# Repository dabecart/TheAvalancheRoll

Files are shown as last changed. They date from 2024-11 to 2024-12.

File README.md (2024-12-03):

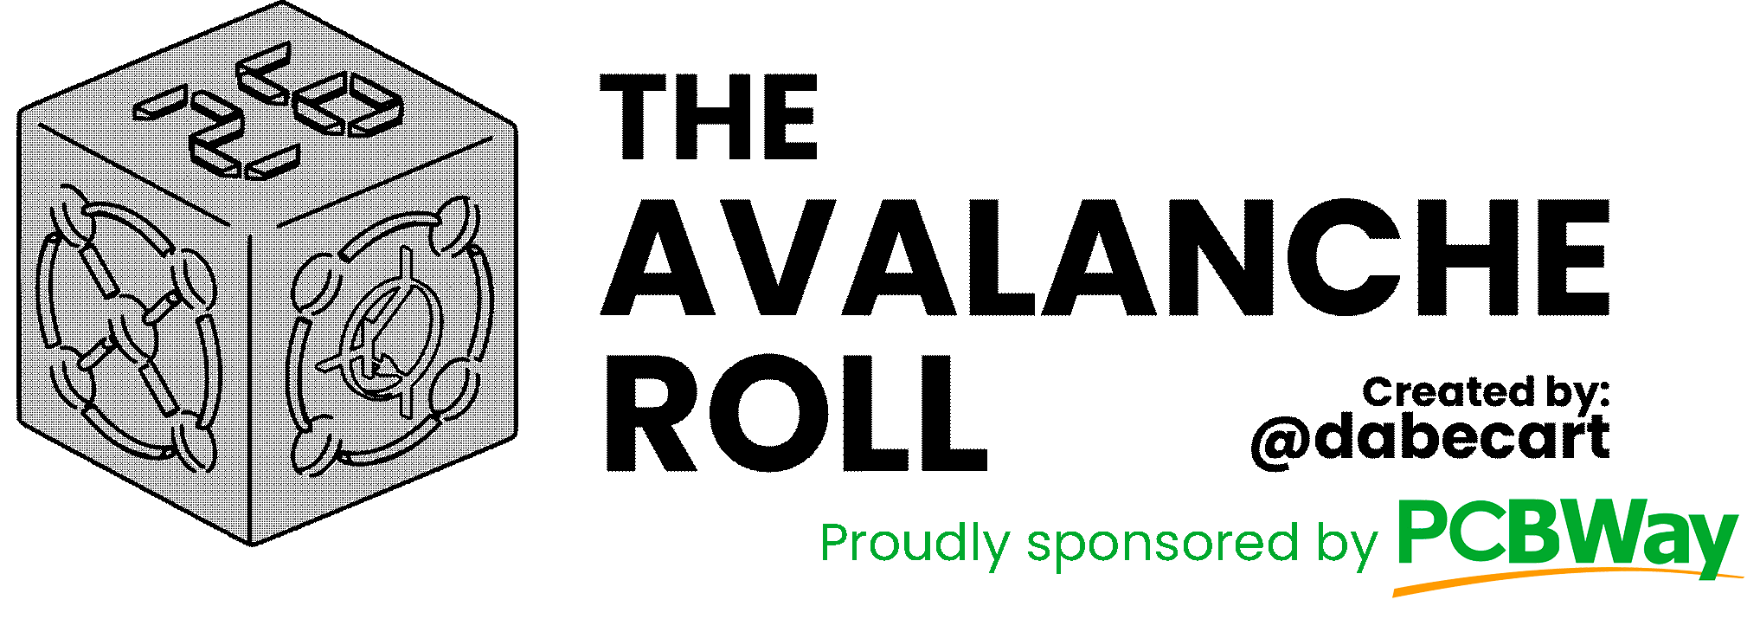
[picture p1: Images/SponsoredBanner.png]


This project was sponsored by [**PCBWay**](#pcbway---pcb-manufacturing-and-assembly)!

# What's **THE AVALANCHE ROLL**?

The Avalanche Roll is the latest (_useless_) invention of @dabecart, and now there's [version 2.0 of this project](#the-avalanche-roll-v20)!

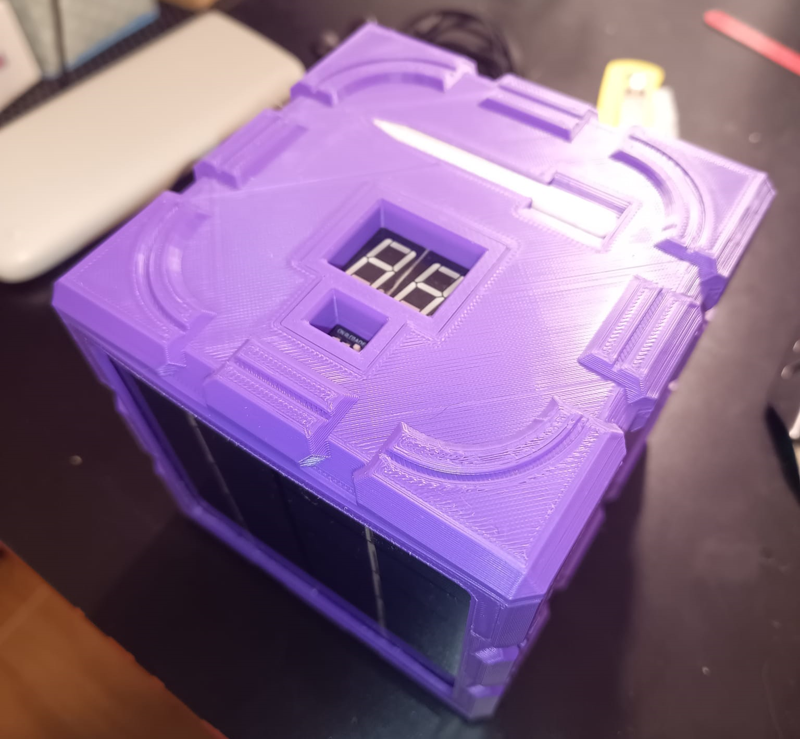
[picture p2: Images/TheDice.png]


It's a space-graded truly-random and up to **D32** electronic dice that operates on a quantum operated phenomenon called **avalanche effect**!

Yes, you've heard it right, avalanche! That's where the name of this hunk of plastic and electronic comes… Genius, Daniel… Genius.

So, the avalanche effect happens when a N-P junction gets _reverse_ polarized, that is, when you try to force current over a diode on the opposite direction, from negative to positive. That, over a long period of time, causes a degrading of the diode, but in this case, we're looking for the exact point where the effect **starts** occurring.

You see, a diode generates a big voltage potential over its two ends when reverse polarized. Electrons cannot jump from one end to the other due to this potential; at least, not according to classical physics. Here comes the quantum part: there's an effect called **quantum tunneling** that actually allows the electrons to “appear” at the other side of the barrier, even though it's supposed to be impossible!

These jumps or magical apparitions are **truly random!** There's no way to calculate when the electrons are going to take the jump, and this is what makes this dice **really** random!

OK. And what about the **space-graded** part?

Well… This dice operates **without any microcontroller!** It's all analogic components and logic gates, meaning that this dice can go to outer space! (I think?) It's one of the requisites, but yeah, it could go to space (I think????).

Oh, and you can select the number of “faces” of the dice! Meaning you can ditch all your boring dices, because you've got one to rule over all!

“But @dabecart, going to space? If it's battery operated, how are you going to charge it?”

Glad you've asked it. It's got a **solar panel**. Yeah… It can also be charged using **USB-C**!

Useless. Over-engineered. Dubious quality. All seals of @dabecart work!

Hope you enjoy it!

# How to use

Please, refer to the [user guide](TheAvalancheRoll_UserGuide.pdf). Thanks!

# How to build it

1. Order (or build) the PCBs. You can find schematics and gerber files in the [PCB folder](PCB).
2. Once you have the PCBs, locate all elements on the boards. You can find a full BOM [here](BOM/TotalBOM.xlsx).
3. Print all the `stl` files. You can locate them [here](3d/stl).
4. Read the [assembly manual](TheAvalancheRoll_AssemblyManual.pdf) and done!

# The Avalanche Roll: v.2.0
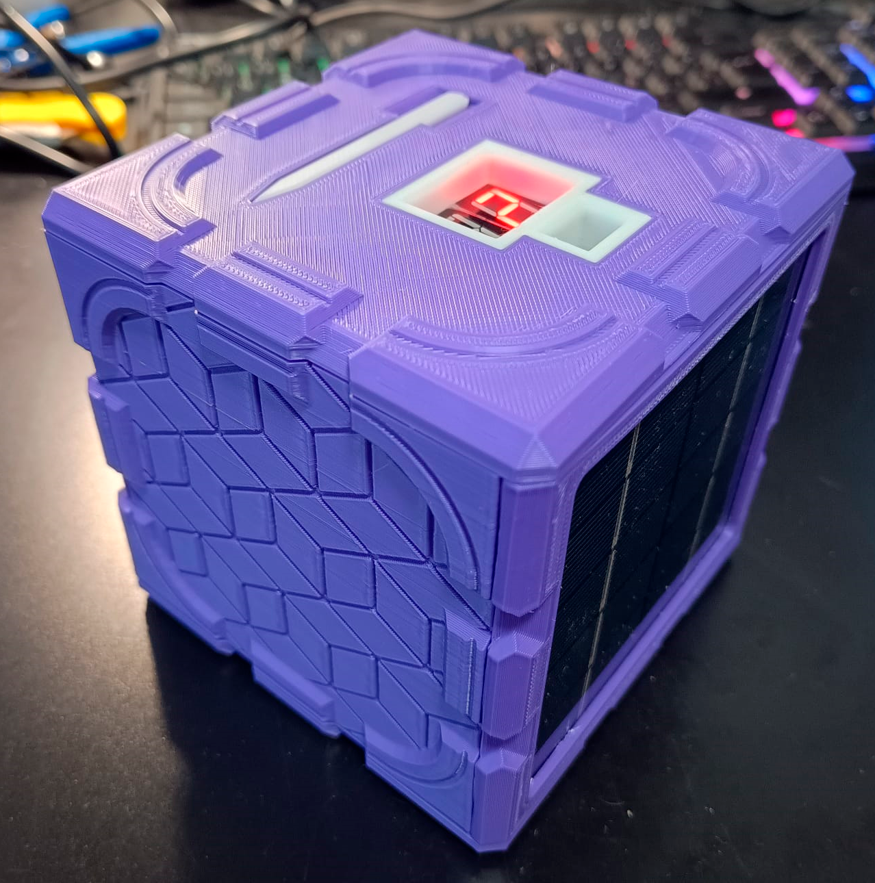
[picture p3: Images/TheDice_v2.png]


When I first launched this project I was really surprised to be approached by the fine gentlemen at PCBWay to sponsor this project. Thanks to them:
- I have been able to fix some of the minor bugs I found on the first version of the dice, such as sporadic number bursts. 
- I've made the power board into a PCB! Yipee! 
- New look! I've also added new patters to the structure of the dice. Hope you like it!

# Photo album

Check the [Google Photos album](https://photos.app.goo.gl/XxesUJSZd3JCvjf18) with photos and a video of the project!



# PCBWay - PCB Manufacturing and Assembly
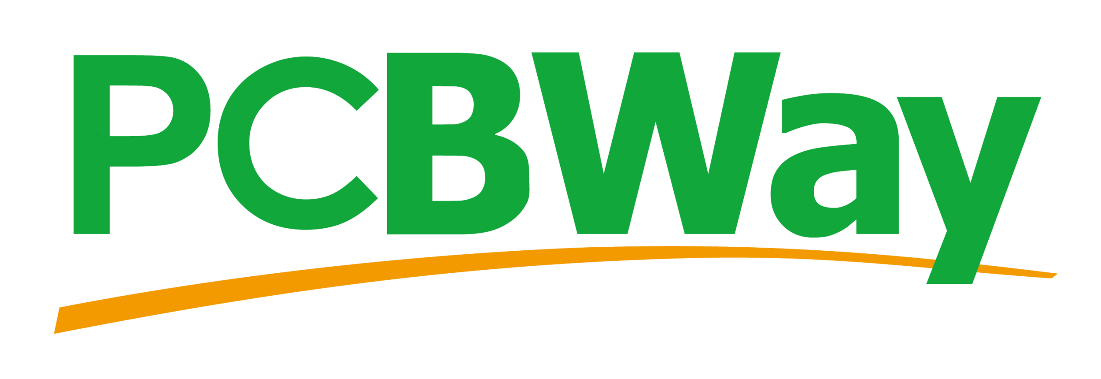
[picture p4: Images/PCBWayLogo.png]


🌟 A Huge Thank You to PCBWay! 🌟

Thanks to PCBWay for their incredible support in bringing the second version of The Avalanche Roll to life. Whether you're a hobbyist, engineer, or student, I feel confident in saying that they're the go-to destination for high-quality PCB manufacturing and prototyping.

Here are just a few of the reasons why PCBWay stands out:

✅ Top-notch Quality: After thoroughly inspecting all of the PCBs of my project, I was content with the great precision the PCBs were made. I felt they are reliable and durable!

✅ Fast Turnaround: The whole ordering, manufacturing and shipping of 50 PCBs to Spain took around a week and a half, which is most impressing! 

✅ Affordable Pricing: Their competitive rates make professional-grade PCBs accessible to everyone. To give you an example, an Avalanche Roll PCB's took less than $5 to build, that is five different PCBs and I'm also counting the shipping, amazing!

✅ Excellent Support: From order placement to final delivery, PCBWay’s team was always there to answer my questions and provide guidance.

Thanks to their expertise and dedication, I was able to turn my ideas for this project into reality without a hitch. If you’re working on your next PCB project, I can’t recommend PCBWay enough!

🎉 Visit [**PCBWay.com**](https://www.pcbway.com/) and experience their amazing service for yourself!

# License
This project is licensed under MIT License. Read the [LICENSE file](LICENSE).

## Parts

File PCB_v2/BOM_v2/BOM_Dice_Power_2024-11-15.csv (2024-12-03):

ID | Name | Designator | Quantity
1 | JST-XH-02 | X5,X4,X3,X2,X1,X6 | 6
2 | LIPO BATTERY CHARGE | U3 | 1
3 | Boost-Converter | U2,U1 | 2
4 | 1N5819RLG | D1,D2 | 2

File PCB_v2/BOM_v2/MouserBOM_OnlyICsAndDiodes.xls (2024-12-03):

THEAVALANCHEROLL
Mouser No | Mfr. No | Manufacturer | Customer No | Description | RoHS | Lifecycle | Order Qty. | Price (EUR) | Ext.: (EUR)
512-1N4148 | 1N4148 | onsemi |  | Small Signal Switching Diodes 100V Io/200mA BULK | RoHS Compliant By Exemption |  | 2 | 0,093 € | 0,19 €
637-1N5819 | 1N5819 | Diotec Semiconductor |  | Schottky Diodes & Rectifiers Schottky, DO-15, 40V, 1A | RoHS Compliant By Exemption |  | 2 | 0,158 € | 0,32 €
637-2N3904 | 2N3904 | Diotec Semiconductor |  | Bipolar Transistors - BJT BJT, TO-92, 40V, 200mA, NPN | RoHS Compliant |  | 2 | 0,093 € | 0,19 €
637-2N7000 | 2N7000 | Diotec Semiconductor |  | MOSFETs MOSFET, TO-92, 60V, 0.2A, 150C, N | RoHS Compliant |  | 38 | 0,112 € | 4,26 €
625-BZX85C5V1-TAP | BZX85C5V1-TAP | Vishay |  | Zener Diodes 5.1 Volt 1.3 Watt 5% | RoHS Compliant By Exemption |  | 1 | 0,186 € | 0,19 €
595-LM324N | LM324N | Texas Instruments |  | Operational Amplifiers - Op Amps Quad | RoHS Compliant |  | 1 | 0,316 € | 0,32 €
595-LM358AP | LM358AP | Texas Instruments |  | Operational Amplifiers - Op Amps Dual | RoHS Compliant |  | 1 | 0,233 € | 0,23 €
595-NE555P | NE555P | Texas Instruments |  | Timers & Support Products Precision | RoHS Compliant |  | 4 | 0,316 € | 1,26 €
512-SS8550DBU | SS8550DBU | onsemi |  | Bipolar Transistors - BJT TO92 PNP 2W BULK | RoHS Compliant |  | 2 | 0,242 € | 0,48 €
595-SN74HC02AN | SN74HC02AN | Texas Instruments |  | Logic Gates | RoHS Compliant |  | 1 | 0,512 € | 0,51 €
595-SN74AHC14N | SN74AHC14N | Texas Instruments |  | Inverters Hex Schmitt-Trigger | RoHS Compliant |  | 2 | 0,372 € | 0,74 €
595-SN74ACT08N | SN74ACT08N | Texas Instruments |  | Logic Gates Quad 2-Input Pos | RoHS Compliant |  | 9 | 0,484 € | 4,36 €
595-SN74HC393N | SN74HC393N | Texas Instruments |  | Counter ICs Dual 4-Bit Binary | RoHS Compliant |  | 1 | 0,512 € | 0,51 €
595-SN74AC86N | SN74AC86N | Texas Instruments |  | Logic Gates Quad 2 Input | RoHS Compliant |  | 1 | 0,465 € | 0,47 €
595-SN74F32N | SN74F32N | Texas Instruments |  | Logic Gates Quad 2-input Positive-OR gates | RoHS Compliant |  | 8 | 0,493 € | 3,94 €

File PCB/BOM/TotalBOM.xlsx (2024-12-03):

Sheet: Sheet3
Row Labels | Sum of Quantity | Price/Item | Price
0.1u | 9 | 0.00 € | 0.00 €
100k | 4 | 0.00 € | 0.00 €
100u | 1 | 0.00 € | 0.00 €
10k | 32 | 0.00 € | 0.00 €
1k | 1 | 0.00 € | 0.00 €
1M | 5 | 0.00 € | 0.00 €
1N4148 | 2 | 0.02 € | 0.04 €
1u | 7 | 0.00 € | 0.00 €
200k | 1 | 0.00 € | 0.00 €
220 | 15 | 0.00 € | 0.00 €
220k | 3 | 0.00 € | 0.00 €
2N3904 | 2 | 0.08 € | 0.16 €
2N7000 | 38 | 0.20 € | 7.45 €
4.7k | 2 | 0.00 € | 0.00 €
4.7u | 1 | 0.00 € | 0.00 €
470k | 3 | 0.00 € | 0.00 €
47k | 2 | 0.00 € | 0.00 €
47n | 2 | 0.00 € | 0.00 €
500k | 1 | 0.00 € | 0.00 €
AlwaysOn | 1 | 0.00 € | 0.00 €
BZX85C5V1 | 1 | 0.15 € | 0.15 €
Digit0 | 1 | 0.20 € | 0.20 €
Digit1 | 1 | 0.20 € | 0.20 €
FromBToA | 2 | 0.00 € | 0.00 €
FromCToB | 2 | 0.00 € | 0.00 €
FromDToC | 2 | 0.00 € | 0.00 €
FromLayerB | 1 | 0.00 € | 0.00 €
FromLayerC | 1 | 0.00 € | 0.00 €
JST-XH-02 | 6 | 0.02 € | 0.12 €
JST-XH-04 | 1 | 0.02 € | 0.02 €
Layer A-B | 1 | 0.00 € | 0.00 €
LM324 | 1 | 0.34 € | 0.34 €
LM358AP | 1 | 0.21 € | 0.21 €
ManualThrow | 1 | 0.00 € | 0.00 €
NC_Tilt | 1 | 0.13 € | 0.13 €
ND_Tilt | 1 | 0.00 € | 0.00 €
NE555P | 4 | 0.38 € | 1.52 €
S8550 | 2 | 0.25 € | 0.50 €
S9014 | 1 | 0.25 € | 0.25 €
S9015 | 3 | 0.25 € | 0.75 €
SN74HC02N | 1 | 0.61 € | 0.61 €
SN74HC04N | 2 | 0.64 € | 1.28 €
SN74HC08N | 9 | 0.64 € | 5.78 €
SN74HC393N | 1 | 0.64 € | 0.64 €
SN74HC86NE4 | 1 | 0.64 € | 0.64 €
SN74HCT32N | 8 | 0.64 € | 5.14 €
SW-520D | 2 | 0.65 € | 1.30 €
Switch | 1 | 0.50 € | 0.50 €
TestPad | 4 | 0.00 € | 0.00 €
ToLayerA | 3 | 0.00 € | 0.00 €
Grand Total | 198 |  | 27.96 €
 | Manufacturing

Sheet: BOM
Source.Name | ID | Name | Designator | Quantity
BOM_Dice_LayerA_2024-10-03.csv | 1 | JST-XH-02 | X2,X1 | 2
BOM_Dice_LayerA_2024-10-03.csv | 2 | TestPad | U3 | 1
BOM_Dice_LayerA_2024-10-03.csv | 3 | 2N7000 | Q22,Q23,Q24,Q25,Q1,Q2,Q3,Q4,Q5,Q6,Q7,Q8,Q9,Q10,Q11,Q12,Q13,Q14,Q15,Q16,Q17,Q18,Q19,Q20,Q21 | 25
BOM_Dice_LayerA_2024-10-03.csv | 4 | 1u | C1 | 1
BOM_Dice_LayerA_2024-10-03.csv | 5 | FromBToA | J1 | 1
BOM_Dice_LayerA_2024-10-03.csv | 6 | Layer A-B | J2 | 1
BOM_Dice_LayerA_2024-10-03.csv | 7 | 220 | R1,R2,R3,R4,R5,R6,R7,R8,R9,R10,R11,R12,R13,R14 | 14
BOM_Dice_LayerA_2024-10-03.csv | 8 | 10k | R15,R16,R17,R18,R19,R20,R21,R22,R23 | 9
BOM_Dice_LayerA_2024-10-03.csv | 9 | Digit0 | SEG0 | 1
BOM_Dice_LayerA_2024-10-03.csv | 10 | Digit1 | SEG1 | 1
BOM_Dice_LayerA_2024-10-03.csv | 11 | Switch | U1 | 1
BOM_Dice_LayerA_2024-10-03.csv | 12 | SN74HC86NE4 | U2 | 1
BOM_Dice_LayerB_2024-10-03.csv | 1 | TestPad | U11 | 1
BOM_Dice_LayerB_2024-10-03.csv | 2 | JST-XH-02 | X1 | 1
BOM_Dice_LayerB_2024-10-03.csv | 3 | 1u | C1 | 1
BOM_Dice_LayerB_2024-10-03.csv | 4 | ToLayerA | H1 | 1
BOM_Dice_LayerB_2024-10-03.csv | 5 | FromBToA | H2 | 1
BOM_Dice_LayerB_2024-10-03.csv | 6 | FromLayerC | J1 | 1
BOM_Dice_LayerB_2024-10-03.csv | 7 | FromCToB | J2 | 1
BOM_Dice_LayerB_2024-10-03.csv | 8 | 2N7000 | Q1 | 1
BOM_Dice_LayerB_2024-10-03.csv | 9 | 10k | R1 | 1
BOM_Dice_LayerB_2024-10-03.csv | 10 | SN74HC08N | U1,U3,U4,U6 | 4
BOM_Dice_LayerB_2024-10-03.csv | 11 | SN74HCT32N | U5,U7,U8,U9,U10 | 5
BOM_Dice_LayerB_2024-10-03.csv | 12 | SN74HC04N | U2 | 1
BOM_Dice_LayerC_2024-10-03.csv | 1 | JST-XH-02 | X1 | 1
BOM_Dice_LayerC_2024-10-03.csv | 2 | TestPad | U11 | 1
BOM_Dice_LayerC_2024-10-03.csv | 3 | FromDToC | J3 | 1
BOM_Dice_LayerC_2024-10-03.csv | 4 | FromLayerB | J1 | 1
BOM_Dice_LayerC_2024-10-03.csv | 5 | 1u | C1 | 1
BOM_Dice_LayerC_2024-10-03.csv | 6 | FromCToB | H2 | 1
BOM_Dice_LayerC_2024-10-03.csv | 7 | FromDToC | J2 | 1
BOM_Dice_LayerC_2024-10-03.csv | 8 | SN74HC04N | U1 | 1
BOM_Dice_LayerC_2024-10-03.csv | 9 | SN74HC08N | U2,U4,U5,U7,U9 | 5
BOM_Dice_LayerC_2024-10-03.csv | 10 | SN74HCT32N | U3,U6,U8 | 3
BOM_Dice_LayerD_2024-10-03.csv | 1 | JST-XH-02 |  | 2
BOM_Dice_LayerD_2024-10-03.csv | 2 | TestPad |  | 1
BOM_Dice_LayerD_2024-10-03.csv | 3 | JST-XH-04 |  | 1
BOM_Dice_LayerD_2024-10-03.csv | 4 | SW-520D |  | 2
BOM_Dice_LayerD_2024-10-03.csv | 5 | AlwaysOn |  | 1
BOM_Dice_LayerD_2024-10-03.csv | 6 | ManualThrow |  | 1
BOM_Dice_LayerD_2024-10-03.csv | 7 | ToLayerA |  | 1
BOM_Dice_LayerD_2024-10-03.csv | 8 | SN74HC02N |  | 1
BOM_Dice_LayerD_2024-10-03.csv | 9 | ToLayerA |  | 1
BOM_Dice_LayerD_2024-10-03.csv | 10 | ND_Tilt |  | 1
BOM_Dice_LayerD_2024-10-03.csv | 11 | NC_Tilt |  | 1
BOM_Dice_LayerD_2024-10-03.csv | 12 | 2N7000 |  | 12
BOM_Dice_LayerD_2024-10-03.csv | 13 | 100k |  | 4
BOM_Dice_LayerD_2024-10-03.csv | 14 | 220k |  | 3
BOM_Dice_LayerD_2024-10-03.csv | 15 | SN74HC393N |  | 1
BOM_Dice_LayerD_2024-10-03.csv | 16 | 47n |  | 2
BOM_Dice_LayerD_2024-10-03.csv | 17 | 0.1u |  | 9
BOM_Dice_LayerD_2024-10-03.csv | 18 | 4.7u |  | 1
BOM_Dice_LayerD_2024-10-03.csv | 19 | 1u |  | 4
BOM_Dice_LayerD_2024-10-03.csv | 20 | 100u |  | 1
BOM_Dice_LayerD_2024-10-03.csv | 21 | BZX85C5V1 |  | 1
BOM_Dice_LayerD_2024-10-03.csv | 22 | 1N4148 |  | 2
BOM_Dice_LayerD_2024-10-03.csv | 23 | 2N3904 |  | 2
BOM_Dice_LayerD_2024-10-03.csv | 24 | S9015 |  | 3
BOM_Dice_LayerD_2024-10-03.csv | 25 | S9014 |  | 1
BOM_Dice_LayerD_2024-10-03.csv | 26 | S8550 |  | 2
BOM_Dice_LayerD_2024-10-03.csv | 27 | 10k |  | 21
BOM_Dice_LayerD_2024-10-03.csv | 28 | 1M |  | 5
BOM_Dice_LayerD_2024-10-03.csv | 29 | 47k |  | 2
BOM_Dice_LayerD_2024-10-03.csv | 30 | 4.7k |  | 2
BOM_Dice_LayerD_2024-10-03.csv | 31 | 470k |  | 3
BOM_Dice_LayerD_2024-10-03.csv | 32 | 1k |  | 1
BOM_Dice_LayerD_2024-10-03.csv | 33 | 220 |  | 1
BOM_Dice_LayerD_2024-10-03.csv | 34 | 200k |  | 1
BOM_Dice_LayerD_2024-10-03.csv | 35 | 500k |  | 1
BOM_Dice_LayerD_2024-10-03.csv | 36 | 10k |  | 1
BOM_Dice_LayerD_2024-10-03.csv | 37 | NE555P |  | 4
BOM_Dice_LayerD_2024-10-03.csv | 38 | LM324 |  | 1
BOM_Dice_LayerD_2024-10-03.csv | 39 | LM358AP |  | 1

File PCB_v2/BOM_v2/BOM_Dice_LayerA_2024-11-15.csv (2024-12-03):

ID | Name | Designator | Quantity
1 | 2N7000 | Q22,Q23,Q24,Q25,Q1,Q2,Q3,Q4,Q5,Q6,Q7,Q8,Q9,Q10,Q11,Q12,Q13,Q14,Q15,Q16,Q17,Q18,Q19,Q20,Q21 | 25
2 | 1u | C1 | 1
3 | FromBToA | J1 | 1
4 | Layer A-B | J2 | 1
5 | 220 | R1,R2,R3,R4,R5,R6,R7,R8,R9,R10,R11,R12,R13,R14 | 14
6 | 10k | R15,R16,R17,R18,R19,R20,R21,R22,R23 | 9
7 | Digit0 | SEG0 | 1
8 | Digit1 | SEG1 | 1
9 | Switch | U1 | 1
10 | SN74HC86NE4 | U2 | 1
11 | JST-XH-02 | X2,X1 | 2
12 | TestPad | U3 | 1

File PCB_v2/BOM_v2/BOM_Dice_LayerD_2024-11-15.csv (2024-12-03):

ID | Name | Designator | Quantity
1 | JST-XH-02 | X3,X1 | 2
2 | TestPad | U11 | 1
3 | JST-XH-04 | X2 | 1
4 | SW-520D | U8,U6 | 2
5 | 0.22u | C7 | 1
6 | 0 | R46,R47 | 2
7 | 2.2u | C8 | 1
8 | 1M | R11,R3,R6,R9,R10,R29 | 6
9 | AlwaysOn | J3 | 1
10 | ManualThrow | J4 | 1
11 | ToLayerA | H2 | 1
12 | SN74HC02N | U12 | 1
13 | ToLayerA | H1 | 1
14 | ND_Tilt | J1 | 1
15 | NC_Tilt | J2 | 1
16 | 2N7000 | Q20,Q7,Q8,Q11,Q12,Q13,Q14,Q15,Q16,Q17,Q18,Q19 | 12
17 | 100k | R44,R13,R25,R34 | 4
18 | 220k | R45,R26,R35 | 3
19 | SN74HC393N | U10 | 1
20 | 47n | C1,C2 | 2
21 | 0.1u | C4,C5,C9,C13,C14,C15,C16,C17 | 8
22 | 4.7u | C3 | 1
23 | 1u | C6,C11,C12 | 3
24 | 100u | C10 | 1
25 | BZX85C5V1 | D1 | 1
26 | 1N4148 | D2,D3 | 2
27 | 2N3904 | Q1,Q2 | 2
28 | S9015 | Q3,Q5,Q9 | 3
29 | S9014 | Q4 | 1
30 | S8550 | Q6,Q10 | 2
31 | 10k | R1,R4,R7,R8,R15,R18,R19,R20,R21,R24,R27,R28,R30,R33,R36,R38,R39,R40,R41,R42,R43 | 21
32 | 47k | R5 | 1
33 | 4.7k | R12,R17 | 2
34 | 470k | R16,R32,R37 | 3
35 | 1k | R23 | 1
36 | 220 | R31 | 1
37 | 200k | R2 | 1
38 | 500k | R14 | 1
39 | 10k | R22 | 1
40 | NE555P | U2,U3,U5,U7 | 4
41 | LM324 | U1 | 1
42 | LM358AP | U4 | 1

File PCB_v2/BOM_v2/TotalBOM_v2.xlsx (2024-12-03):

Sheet: Sheet2
Row Labels | Sum of Quantity
0 | 2
0.1u | 8
0.22u | 1
100k | 4
100u | 1
10k | 32
1k | 1
1M | 6
1N4148 | 2
1N5819RLG | 2
1u | 6
2.2u | 1
200k | 1
220 | 15
220k | 3
2N3904 | 2
2N7000 | 38
4.7k | 2
4.7u | 1
470k | 3
47k | 1
47n | 2
500k | 1
AlwaysOn | 1 | x
Boost-Converter | 2
BZX85C5V1 | 1
Digit0 | 1
Digit1 | 1
FromBToA | 2 | x
FromCToB | 2 | x
FromDToC | 2 | x
FromLayerB | 1 | x
FromLayerC | 1 | x
JST-XH-02 | 12
JST-XH-04 | 1
Layer A-B | 1
LIPO BATTERY CHARGE | 1
LM324 | 1
LM358AP | 1
ManualThrow | 1 | x
NC_Tilt | 1 | x
ND_Tilt | 1 | x
NE555P | 4
S8550 | 2
S9014 | 1
S9015 | 3
SN74HC02N | 1
SN74HC04N | 2
SN74HC08N | 9
SN74HC393N | 1
SN74HC86NE4 | 1
SN74HCT32N | 8
SW-520D | 2
Switch | 1 | x
TestPad | 4 | x
ToLayerA | 3 | x
(blank) |  | x
Grand Total | 211

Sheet: BOM_v2
Source.Name | ID | Name | Designator | Quantity
BOM_Dice_LayerA_2024-11-15.csv | 1 | 2N7000 | Q22,Q23,Q24,Q25,Q1,Q2,Q3,Q4,Q5,Q6,Q7,Q8,Q9,Q10,Q11,Q12,Q13,Q14,Q15,Q16,Q17,Q18,Q19,Q20,Q21 | 25
BOM_Dice_LayerA_2024-11-15.csv | 2 | 1u | C1 | 1
BOM_Dice_LayerA_2024-11-15.csv | 3 | FromBToA | J1 | 1
BOM_Dice_LayerA_2024-11-15.csv | 4 | Layer A-B | J2 | 1
BOM_Dice_LayerA_2024-11-15.csv | 5 | 220 | R1,R2,R3,R4,R5,R6,R7,R8,R9,R10,R11,R12,R13,R14 | 14
BOM_Dice_LayerA_2024-11-15.csv | 6 | 10k | R15,R16,R17,R18,R19,R20,R21,R22,R23 | 9
BOM_Dice_LayerA_2024-11-15.csv | 7 | Digit0 | SEG0 | 1
BOM_Dice_LayerA_2024-11-15.csv | 8 | Digit1 | SEG1 | 1
BOM_Dice_LayerA_2024-11-15.csv | 9 | Switch | U1 | 1
BOM_Dice_LayerA_2024-11-15.csv | 10 | SN74HC86NE4 | U2 | 1
BOM_Dice_LayerA_2024-11-15.csv | 11 | JST-XH-02 | X2,X1 | 2
BOM_Dice_LayerA_2024-11-15.csv | 12 | TestPad | U3 | 1
BOM_Dice_LayerB_2024-11-15.csv | 1 | TestPad | U11 | 1
BOM_Dice_LayerB_2024-11-15.csv | 2 | JST-XH-02 | X1 | 1
BOM_Dice_LayerB_2024-11-15.csv | 3 | 1u | C1 | 1
BOM_Dice_LayerB_2024-11-15.csv | 4 | ToLayerA | H1 | 1
BOM_Dice_LayerB_2024-11-15.csv | 5 | FromBToA | H2 | 1
BOM_Dice_LayerB_2024-11-15.csv | 6 | FromLayerC | J1 | 1
BOM_Dice_LayerB_2024-11-15.csv | 7 | FromCToB | J2 | 1
BOM_Dice_LayerB_2024-11-15.csv | 8 | 2N7000 | Q1 | 1
BOM_Dice_LayerB_2024-11-15.csv | 9 | 10k | R1 | 1
BOM_Dice_LayerB_2024-11-15.csv | 10 | SN74HC08N | U1,U3,U4,U6 | 4
BOM_Dice_LayerB_2024-11-15.csv | 11 | SN74HCT32N | U5,U7,U8,U9,U10 | 5
BOM_Dice_LayerB_2024-11-15.csv | 12 | SN74HC04N | U2 | 1
BOM_Dice_LayerC_2024-11-15.csv | 1 | JST-XH-02 | X1 | 1
BOM_Dice_LayerC_2024-11-15.csv | 2 | TestPad | U11 | 1
BOM_Dice_LayerC_2024-11-15.csv | 3 | FromDToC | J3 | 1
BOM_Dice_LayerC_2024-11-15.csv | 4 | FromLayerB | J1 | 1
BOM_Dice_LayerC_2024-11-15.csv | 5 | 1u | C1 | 1
BOM_Dice_LayerC_2024-11-15.csv | 6 | FromCToB | H2 | 1
BOM_Dice_LayerC_2024-11-15.csv | 7 | FromDToC | J2 | 1
BOM_Dice_LayerC_2024-11-15.csv | 8 | SN74HC04N | U1 | 1
BOM_Dice_LayerC_2024-11-15.csv | 9 | SN74HC08N | U2,U4,U5,U7,U9 | 5
BOM_Dice_LayerC_2024-11-15.csv | 10 | SN74HCT32N | U3,U6,U8 | 3
BOM_Dice_LayerD_2024-11-15.csv | 1 | JST-XH-02 | X3,X1 | 2
BOM_Dice_LayerD_2024-11-15.csv | 2 | TestPad | U11 | 1
BOM_Dice_LayerD_2024-11-15.csv | 3 | JST-XH-04 | X2 | 1
BOM_Dice_LayerD_2024-11-15.csv | 4 | SW-520D | U8,U6 | 2
BOM_Dice_LayerD_2024-11-15.csv | 5 | 0.22u | C7 | 1
BOM_Dice_LayerD_2024-11-15.csv | 6 | 0 | R46,R47 | 2
BOM_Dice_LayerD_2024-11-15.csv | 7 | 2.2u | C8 | 1
BOM_Dice_LayerD_2024-11-15.csv | 8 | 1M | R11,R3,R6,R9,R10,R29 | 6
BOM_Dice_LayerD_2024-11-15.csv | 9 | AlwaysOn | J3 | 1
BOM_Dice_LayerD_2024-11-15.csv | 10 | ManualThrow | J4 | 1
BOM_Dice_LayerD_2024-11-15.csv | 11 | ToLayerA | H2 | 1
BOM_Dice_LayerD_2024-11-15.csv | 12 | SN74HC02N | U12 | 1
BOM_Dice_LayerD_2024-11-15.csv | 13 | ToLayerA | H1 | 1
BOM_Dice_LayerD_2024-11-15.csv | 14 | ND_Tilt | J1 | 1
BOM_Dice_LayerD_2024-11-15.csv | 15 | NC_Tilt | J2 | 1
BOM_Dice_LayerD_2024-11-15.csv | 16 | 2N7000 | Q20,Q7,Q8,Q11,Q12,Q13,Q14,Q15,Q16,Q17,Q18,Q19 | 12
BOM_Dice_LayerD_2024-11-15.csv | 17 | 100k | R44,R13,R25,R34 | 4
BOM_Dice_LayerD_2024-11-15.csv | 18 | 220k | R45,R26,R35 | 3
BOM_Dice_LayerD_2024-11-15.csv | 19 | SN74HC393N | U10 | 1
BOM_Dice_LayerD_2024-11-15.csv | 20 | 47n | C1,C2 | 2
BOM_Dice_LayerD_2024-11-15.csv | 21 | 0.1u | C4,C5,C9,C13,C14,C15,C16,C17 | 8
BOM_Dice_LayerD_2024-11-15.csv | 22 | 4.7u | C3 | 1
BOM_Dice_LayerD_2024-11-15.csv | 23 | 1u | C6,C11,C12 | 3
BOM_Dice_LayerD_2024-11-15.csv | 24 | 100u | C10 | 1
BOM_Dice_LayerD_2024-11-15.csv | 25 | BZX85C5V1 | D1 | 1
BOM_Dice_LayerD_2024-11-15.csv | 26 | 1N4148 | D2,D3 | 2
BOM_Dice_LayerD_2024-11-15.csv | 27 | 2N3904 | Q1,Q2 | 2
BOM_Dice_LayerD_2024-11-15.csv | 28 | S9015 | Q3,Q5,Q9 | 3
BOM_Dice_LayerD_2024-11-15.csv | 29 | S9014 | Q4 | 1
BOM_Dice_LayerD_2024-11-15.csv | 30 | S8550 | Q6,Q10 | 2
BOM_Dice_LayerD_2024-11-15.csv | 31 | 10k | R1,R4,R7,R8,R15,R18,R19,R20,R21,R24,R27,R28,R30,R33,R36,R38,R39,R40,R41,R42,R43 | 21
BOM_Dice_LayerD_2024-11-15.csv | 32 | 47k | R5 | 1
BOM_Dice_LayerD_2024-11-15.csv | 33 | 4.7k | R12,R17 | 2
BOM_Dice_LayerD_2024-11-15.csv | 34 | 470k | R16,R32,R37 | 3
BOM_Dice_LayerD_2024-11-15.csv | 35 | 1k | R23 | 1
BOM_Dice_LayerD_2024-11-15.csv | 36 | 220 | R31 | 1
BOM_Dice_LayerD_2024-11-15.csv | 37 | 200k | R2 | 1
BOM_Dice_LayerD_2024-11-15.csv | 38 | 500k | R14 | 1
BOM_Dice_LayerD_2024-11-15.csv | 39 | 10k | R22 | 1
BOM_Dice_LayerD_2024-11-15.csv | 40 | NE555P | U2,U3,U5,U7 | 4
BOM_Dice_LayerD_2024-11-15.csv | 41 | LM324 | U1 | 1
BOM_Dice_LayerD_2024-11-15.csv | 42 | LM358AP | U4 | 1
BOM_Dice_Power_2024-11-15.csv | 1 | JST-XH-02 | X5,X4,X3,X2,X1,X6 | 6
BOM_Dice_Power_2024-11-15.csv | 2 | LIPO BATTERY CHARGE | U3 | 1
BOM_Dice_Power_2024-11-15.csv | 3 | Boost-Converter | U2,U1 | 2
BOM_Dice_Power_2024-11-15.csv | 4 | 1N5819RLG | D1,D2 | 2

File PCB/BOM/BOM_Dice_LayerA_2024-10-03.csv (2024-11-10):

ID | Name | Designator | Quantity
1 | JST-XH-02 | X2,X1 | 2
2 | TestPad | U3 | 1
3 | 2N7000 | Q22,Q23,Q24,Q25,Q1,Q2,Q3,Q4,Q5,Q6,Q7,Q8,Q9,Q10,Q11,Q12,Q13,Q14,Q15,Q16,Q17,Q18,Q19,Q20,Q21 | 25
4 | 1u | C1 | 1
5 | FromBToA | J1 | 1
6 | Layer A-B | J2 | 1
7 | 220 | R1,R2,R3,R4,R5,R6,R7,R8,R9,R10,R11,R12,R13,R14 | 14
8 | 10k | R15,R16,R17,R18,R19,R20,R21,R22,R23 | 9
9 | Digit0 | SEG0 | 1
10 | Digit1 | SEG1 | 1
11 | Switch | U1 | 1
12 | SN74HC86NE4 | U2 | 1

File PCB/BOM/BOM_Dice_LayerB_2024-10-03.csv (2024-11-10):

ID | Name | Designator | Quantity
1 | TestPad | U11 | 1
2 | JST-XH-02 | X1 | 1
3 | 1u | C1 | 1
4 | ToLayerA | H1 | 1
5 | FromBToA | H2 | 1
6 | FromLayerC | J1 | 1
7 | FromCToB | J2 | 1
8 | 2N7000 | Q1 | 1
9 | 10k | R1 | 1
10 | SN74HC08N | U1,U3,U4,U6 | 4
11 | SN74HCT32N | U5,U7,U8,U9,U10 | 5
12 | SN74HC04N | U2 | 1

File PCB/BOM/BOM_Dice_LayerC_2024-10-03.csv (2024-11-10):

ID | Name | Designator | Quantity
1 | JST-XH-02 | X1 | 1
2 | TestPad | U11 | 1
3 | FromDToC | J3 | 1
4 | FromLayerB | J1 | 1
5 | 1u | C1 | 1
6 | FromCToB | H2 | 1
7 | FromDToC | J2 | 1
8 | SN74HC04N | U1 | 1
9 | SN74HC08N | U2,U4,U5,U7,U9 | 5
10 | SN74HCT32N | U3,U6,U8 | 3

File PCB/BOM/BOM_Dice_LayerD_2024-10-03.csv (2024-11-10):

ID | Name | Quantity
1 | JST-XH-02 | 2
2 | TestPad | 1
3 | JST-XH-04 | 1
4 | SW-520D | 2
5 | AlwaysOn | 1
6 | ManualThrow | 1
7 | ToLayerA | 1
8 | SN74HC02N | 1
9 | ToLayerA | 1
10 | ND_Tilt | 1
11 | NC_Tilt | 1
12 | 2N7000 | 12
13 | 100k | 4
14 | 220k | 3
15 | SN74HC393N | 1
16 | 47n | 2
17 | 0.1u | 9
18 | 4.7u | 1
19 | 1u | 4
20 | 100u | 1
21 | BZX85C5V1 | 1
22 | 1N4148 | 2
23 | 2N3904 | 2
24 | S9015 | 3
25 | S9014 | 1
26 | S8550 | 2
27 | 10k | 21
28 | 1M | 5
29 | 47k | 2
30 | 4.7k | 2
31 | 470k | 3
32 | 1k | 1
33 | 220 | 1
34 | 200k | 1
35 | 500k | 1
36 | 10k | 1
37 | NE555P | 4
38 | LM324 | 1
39 | LM358AP | 1

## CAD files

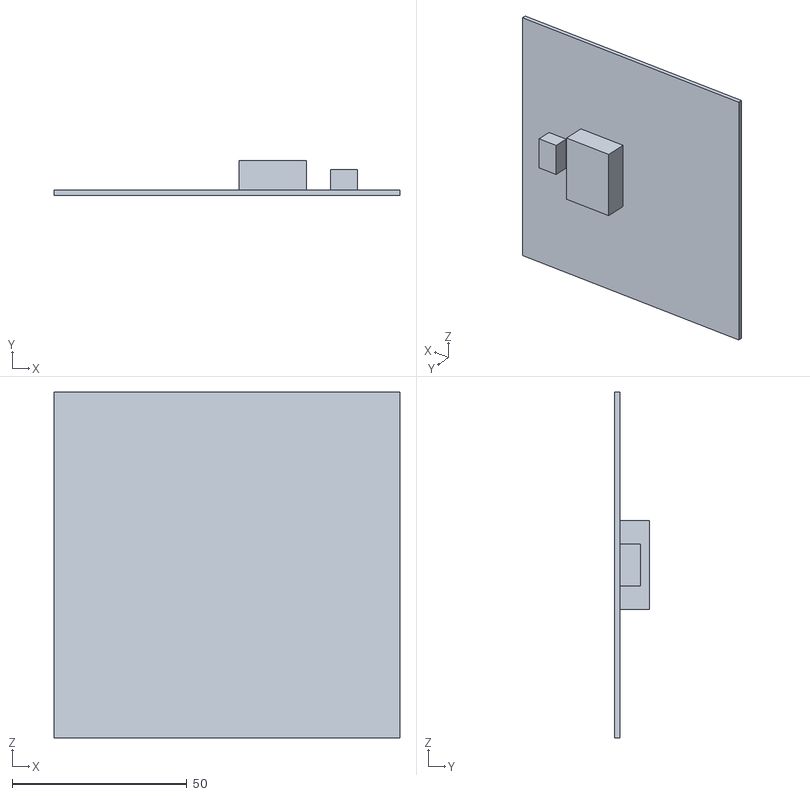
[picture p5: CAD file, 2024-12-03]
3d/stl/Dice_v2 - PCB_Top^Dice_v2-1.STL
99.1 x 10.0 x 99.1

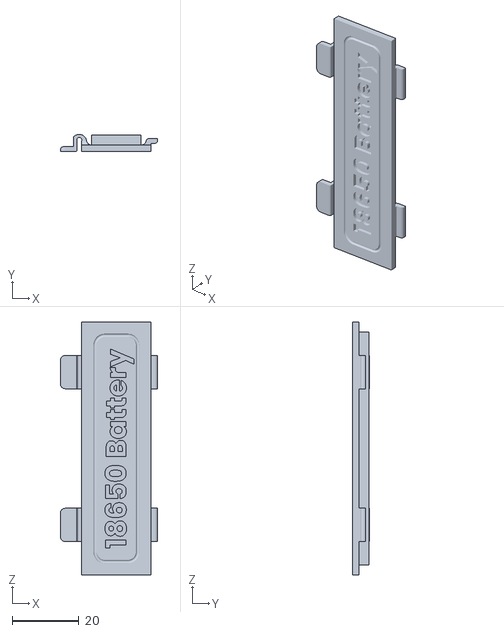
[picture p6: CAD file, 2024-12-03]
3d/stl_v2/Dice_v2 - BatteryLid^Dice_v2-1.STL
29.2 x 5.20 x 75.8

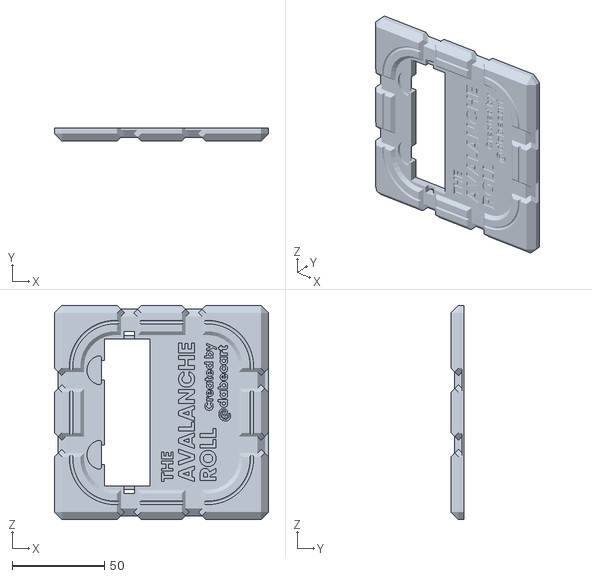
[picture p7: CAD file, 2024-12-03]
3d/stl_v2/Dice_v2 - Dice_Base-1.STL
116.0 x 7.00 x 116.0

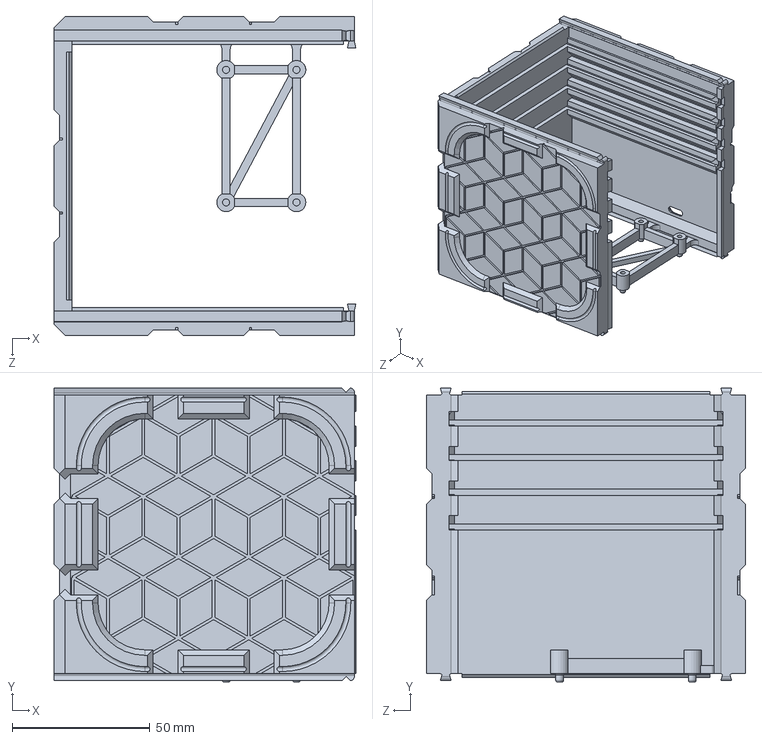
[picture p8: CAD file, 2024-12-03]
3d/Dice_Side.SLDPRT
109.8 x 106.9 x 116.0 mm

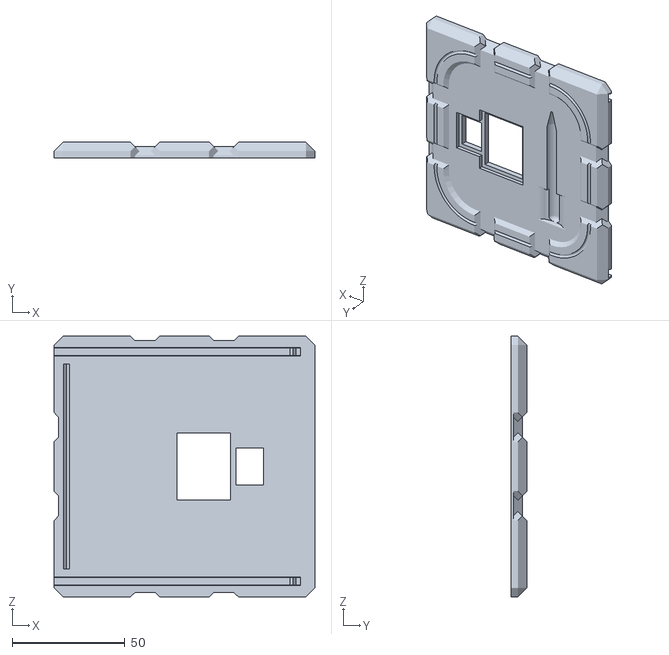
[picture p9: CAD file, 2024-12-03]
3d/stl_v2/Dice_v2 - Dice_Top-1.STL
116.0 x 7.00 x 116.0

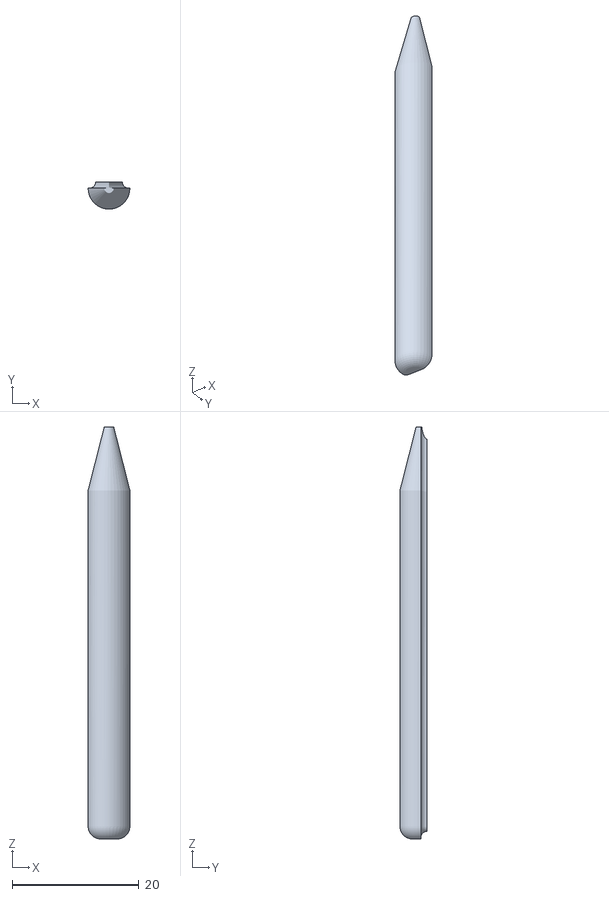
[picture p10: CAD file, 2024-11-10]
3d/stl_v2/Dice_v2 - Pen^Dice_v2-1.STL
6.60 x 4.30 x 65.0

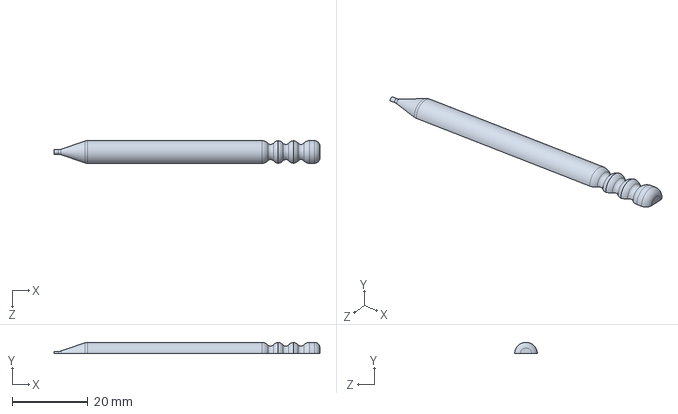
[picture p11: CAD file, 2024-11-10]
3d/Dice_Pen.SLDPRT
70.0 x 3.00 x 6.00 mm

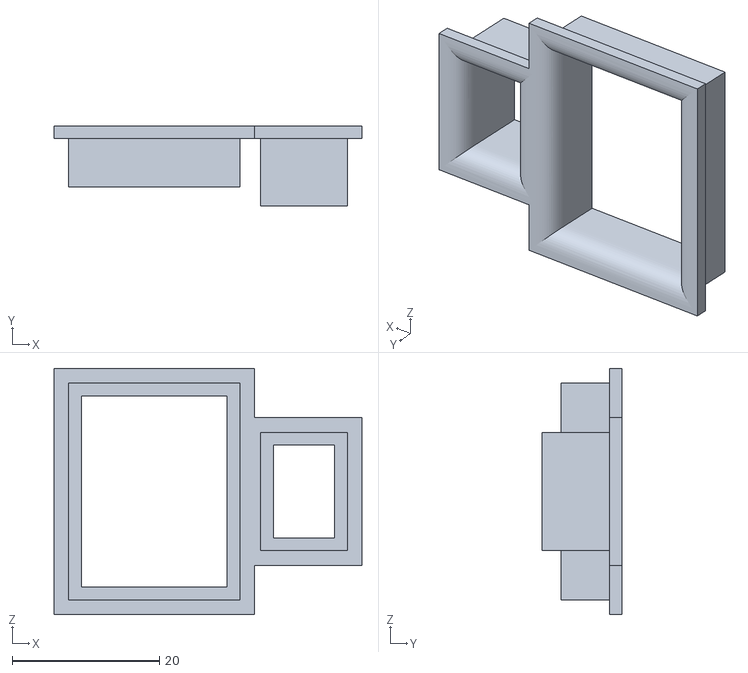
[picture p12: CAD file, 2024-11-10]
3d/stl_v2/Dice_v2 - SegmentUnion^Dice_v2-1.STL
41.9 x 10.9 x 33.5

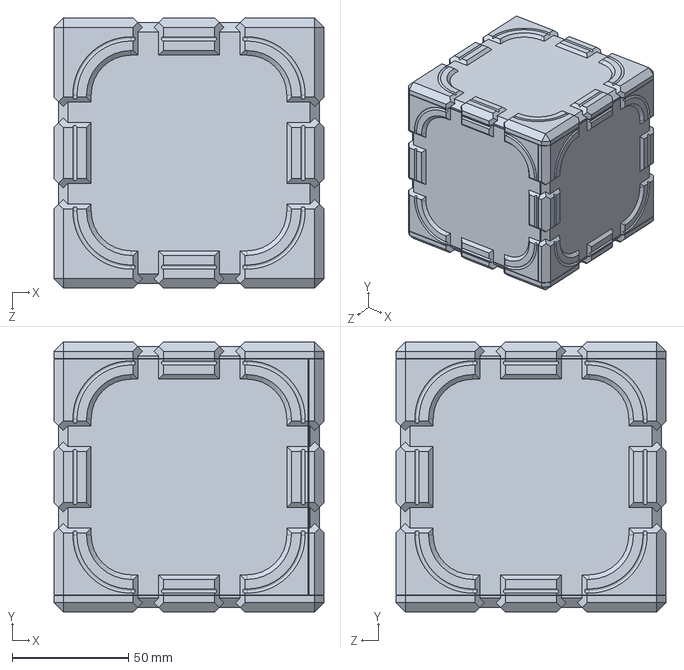
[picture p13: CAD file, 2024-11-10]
3d/Dice_Cube.SLDPRT
116.0 x 116.0 x 116.0 mm

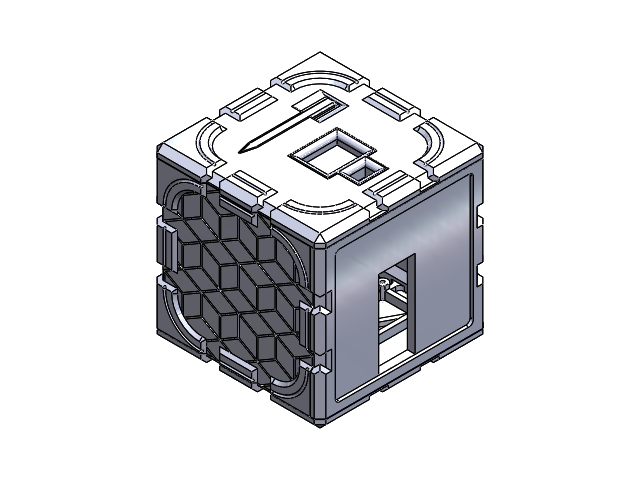
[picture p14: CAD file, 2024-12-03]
3d/Dice_v2.SLDASM
Dice_Front
Dice_Base
Dice_Side
Dice_Top
PCB_Top^Dice_v2
SegmentUnion^Dice_v2
BatteryHolder^Dice_v2
BatteryLid^Dice_v2
Pen^Dice_v2

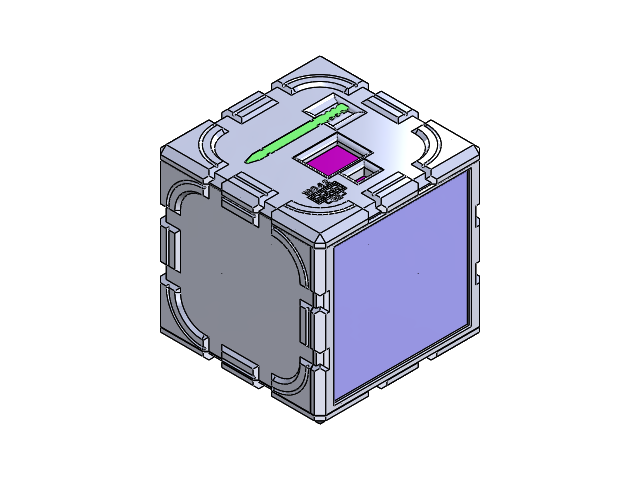
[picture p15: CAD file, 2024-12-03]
3d/save/Dice_Assembly1.SLDASM
Dice_Lid
Dice_Front
Dice_Base
Dice_PCBRack
BatteryLid^Dice_Assembly
SolarPanel^Dice_Assembly
PCB_Top^Dice_Assembly
7Segment_Adapter^Dice_Assembly
Dice_Pen

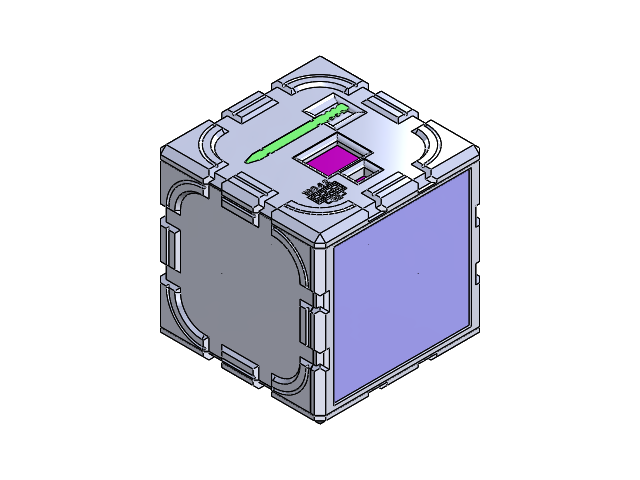
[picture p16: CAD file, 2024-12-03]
3d/save/Dice_Assembly2.SLDASM
Dice_Lid
Dice_Front
Dice_Base
Dice_PCBRack
BatteryLid^Dice_Assembly
SolarPanel^Dice_Assembly
PCB_Top^Dice_Assembly
7Segment_Adapter^Dice_Assembly
Dice_Pen

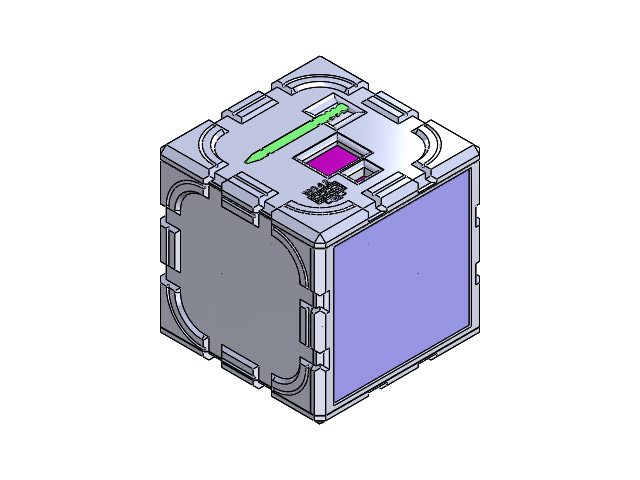
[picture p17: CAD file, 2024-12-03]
3d/save/Dice_Assembly4.SLDASM
Dice_Lid
Dice_Front
Dice_Base
Dice_PCBRack
BatteryLid^Dice_Assembly
SolarPanel^Dice_Assembly
PCB_Top^Dice_Assembly
7Segment_Adapter^Dice_Assembly
Dice_Pen

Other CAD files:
3d/Dice_Top.SLDPRT
3d/stl_v2/Dice_v2 - Dice_Side-1.STL
3d/Dice_Base.SLDPRT
3d/Dice_Front.SLDPRT
3d/Dice_Lid.SLDPRT
3d/Dice_PCBRack.SLDPRT
3d/Logo_Dice.SLDPRT
3d/stl_v2/Dice_v2 - BatteryHolder^Dice_v2-1.STL
3d/stl_v2/Dice_v2 - Dice_Front-1.STL
Logo/DiceSymbol.blend
Logo/Transistor.blend

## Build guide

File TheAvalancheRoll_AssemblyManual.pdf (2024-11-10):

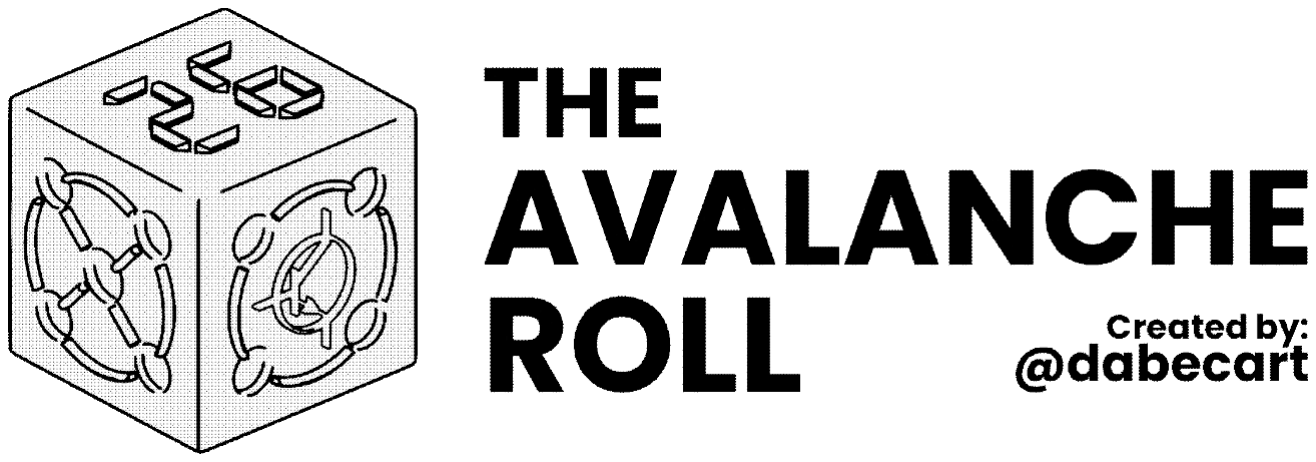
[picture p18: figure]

## github.com/dabecart/TheAvalancheRoll

# Assembly Manual

1

st Edition
9

th of November, 2024

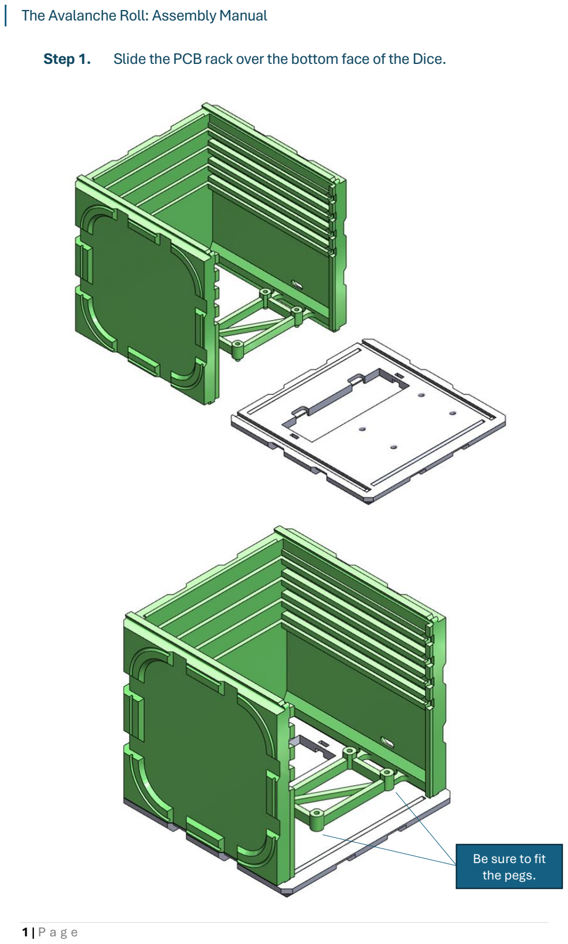
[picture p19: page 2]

The Avalanche Roll: Assembly Manual

1 | P a g e
Step 1. Slide the PCB rack over the bottom face of the Dice.

Be sure to fit
the pegs.

By @dabecart

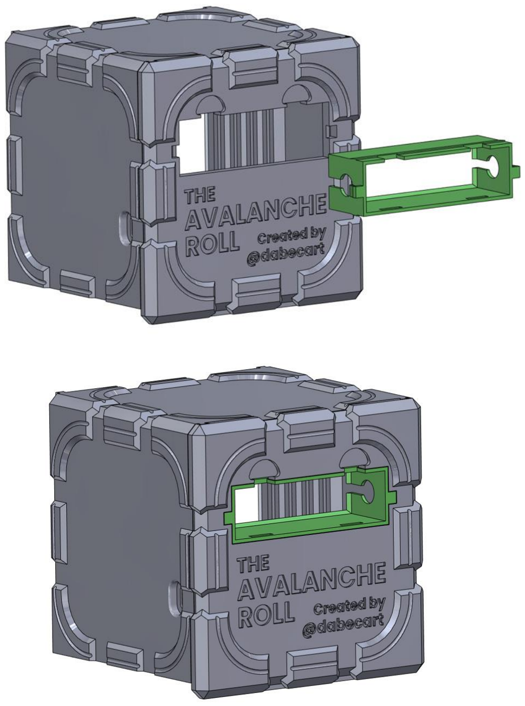
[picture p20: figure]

2 | P a g e
Step 2. Insert the battery case holder on the rectangular hole of the base.

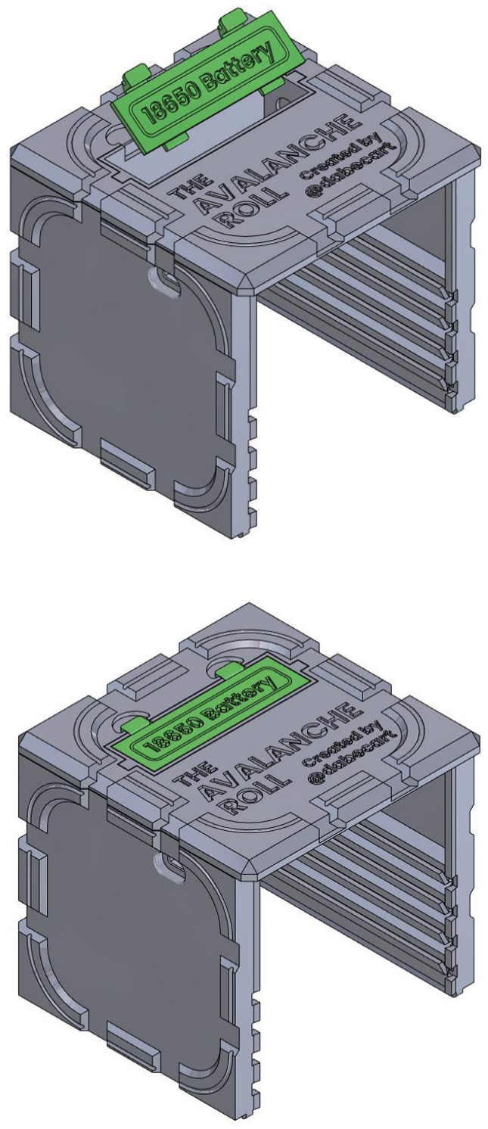
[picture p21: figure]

3 | P a g e
Step 3. Push the battery lid in place.

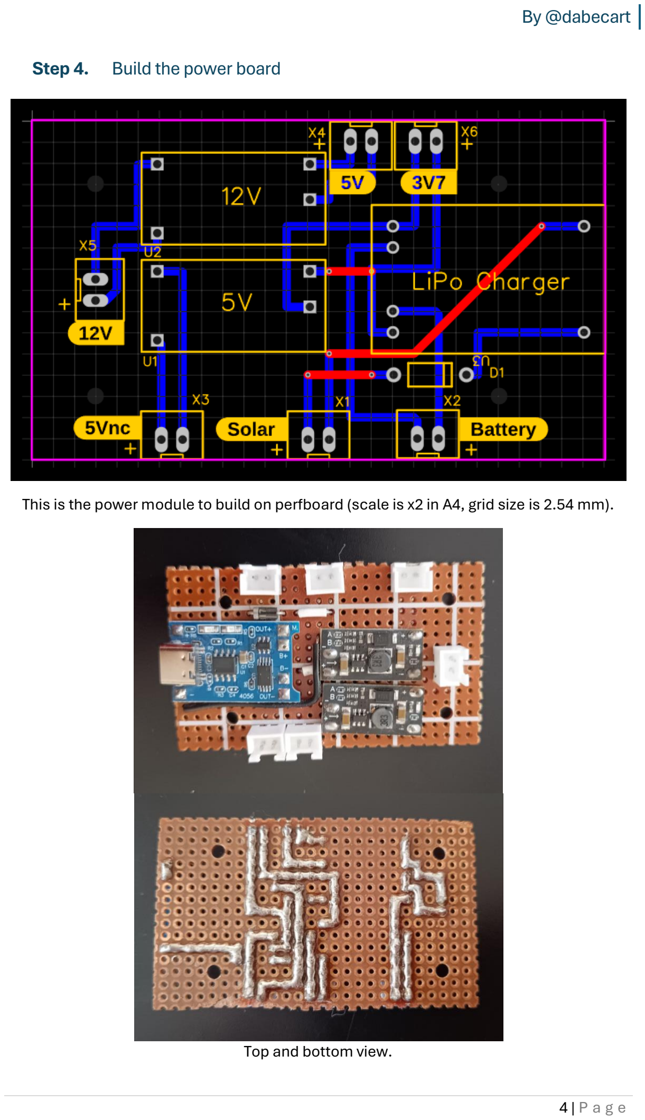
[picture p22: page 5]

Step 4. Build the power board

This is the power module to build on perfboard (scale is x2 in A4, grid size is 2.54 mm).

Top and bottom view.

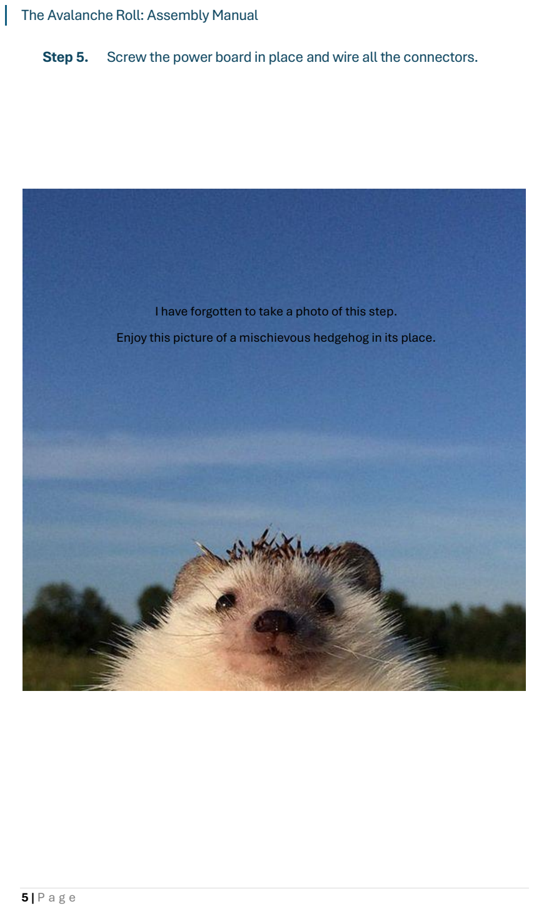
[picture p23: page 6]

5 | P a g e
Step 5. Screw the power board in place and wire all the connectors.

I have forgotten to take a photo of this step.
Enjoy this picture of a mischievous hedgehog in its place.

Step 6. Slide the PCBs in the rails of the rack.

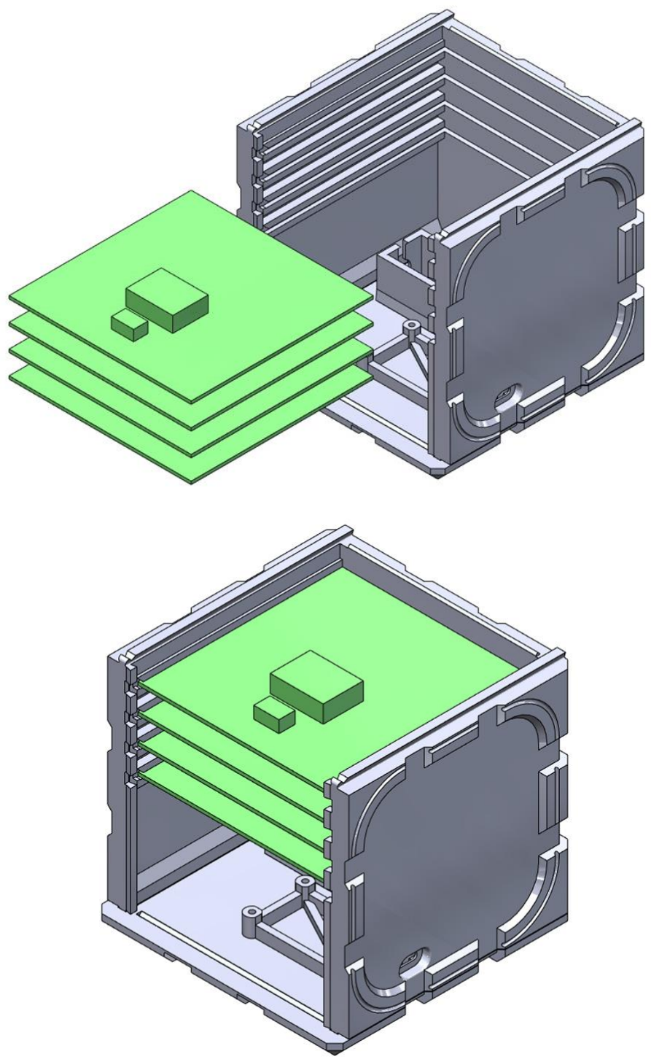
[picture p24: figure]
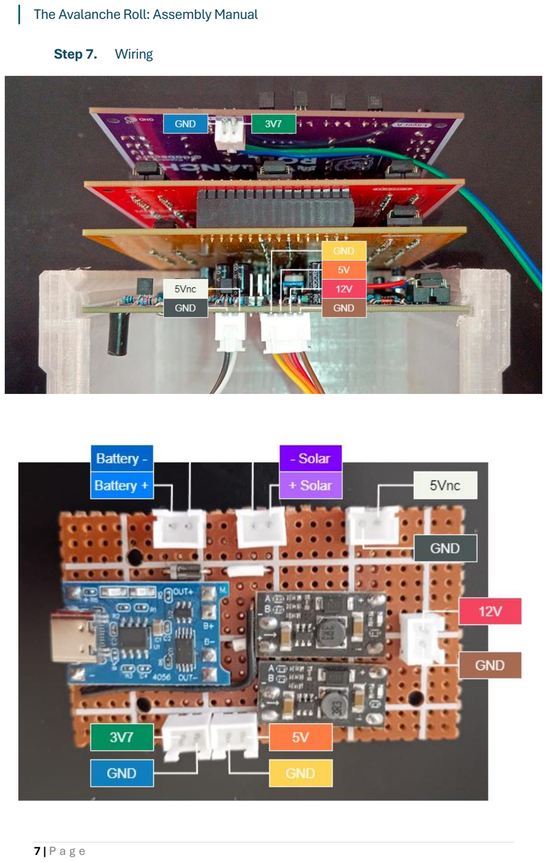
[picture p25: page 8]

7 | P a g e
Step 7. Wiring

Step 8. Slide the front face of the Dice with its solar panel in place.

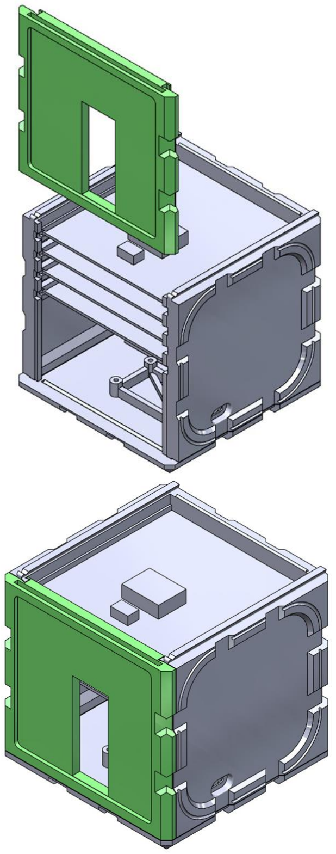
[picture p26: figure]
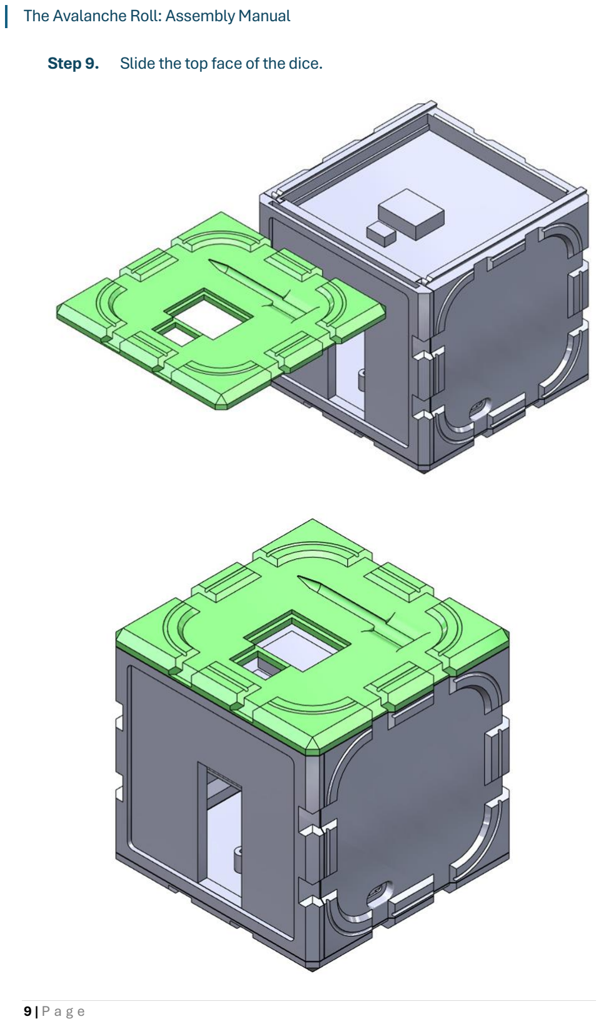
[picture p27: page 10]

9 | P a g e
Step 9. Slide the top face of the dice.

Step 10. Push the display and switch protector in the holes of the top face.

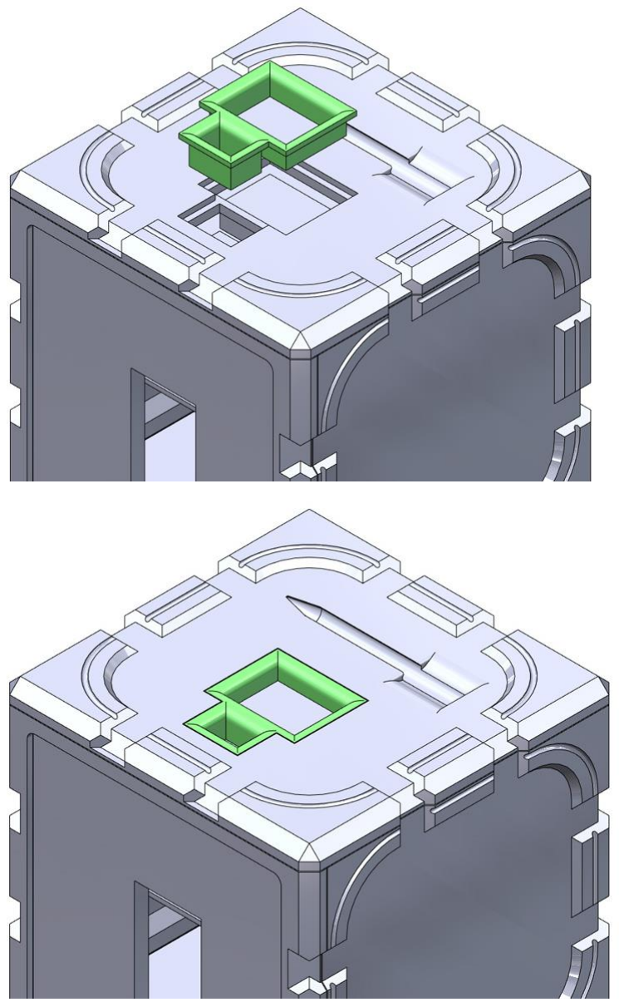
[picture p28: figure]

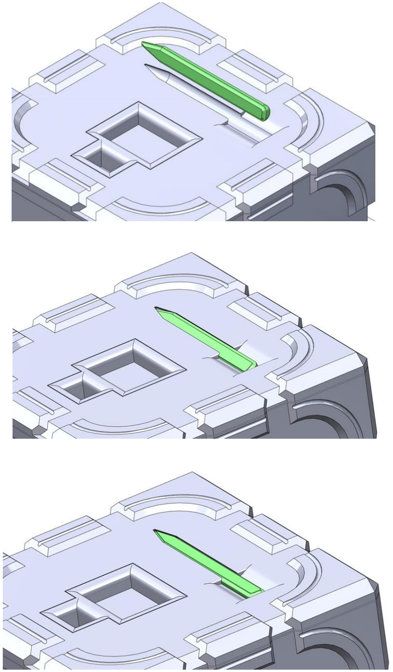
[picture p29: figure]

11 | P a g e
Step 11. Put the pen inside its bracket and rotate it until it fits.

# Done!

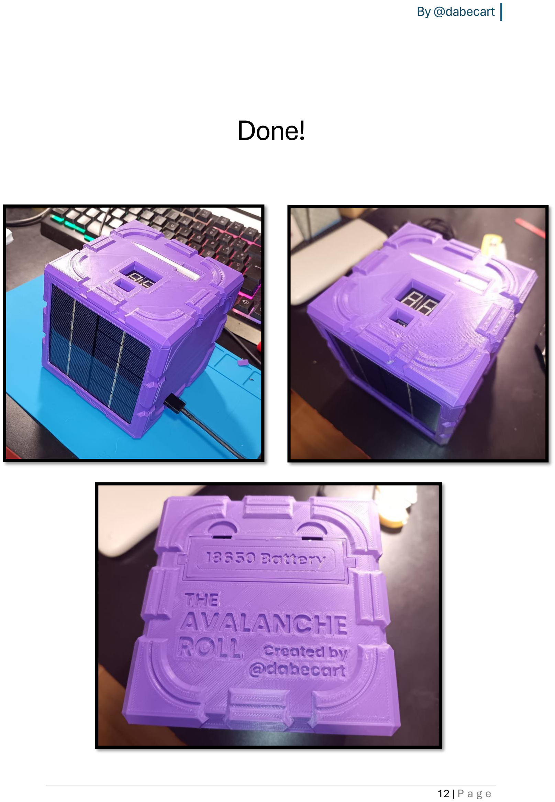
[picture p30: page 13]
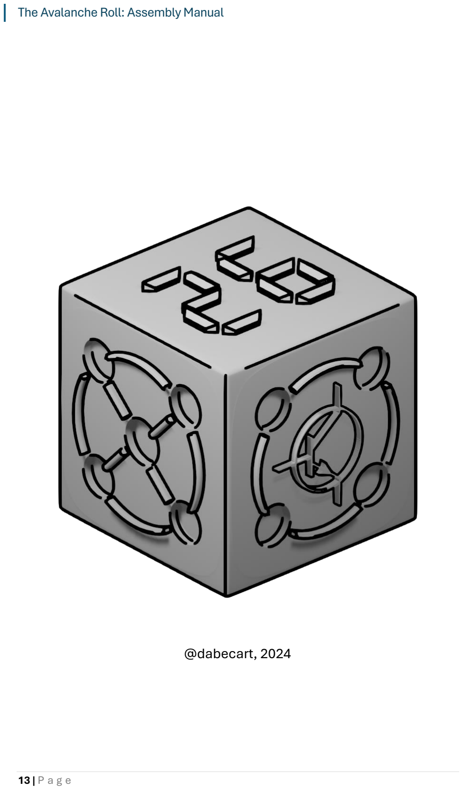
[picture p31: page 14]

13 | P a g e

@dabecart, 2024

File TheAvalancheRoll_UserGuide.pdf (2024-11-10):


## github.com/dabecart/TheAvalancheRoll

# User Guide

1

### st Edition 10th of November, 2024

### The Avalanche Roll: User Guide

1 | P a g e

# What’s THE AVALANCHE ROLL?

The Avalanche Roll is the latest (useless) invention of @dabecart.
It’s a space-graded truly-random and up to D32 electronic dice that operates on a quantum operated phenomenon called avalanche effect!
Yes, you’ve heard it right, avalanche! That’s where the name of this hunk of plastic and electronic comes… Genius, Daniel… Genius.
So, the avalanche effect happens when a N-P junction gets reverse polarized, that is, when you try to force current over a diode on the opposite direction, from negative to positive. That, over a long period of time, causes a degrading of the diode, but in this case, we’re looking for the exact point where the effect starts occurring.
You see, a diode generates a big voltage potential over its two ends when reverse polarized. Electrons cannot jump from one end to the other due to this potential; at least, not according to classical physics. Here comes the quantum part: there’s an effect called quantum tunneling that actually allows the electrons to “appear” at the other side of the barrier, even though it’s supposed to be impossible!
These jumps or magical apparitions are truly random! There’s no way to calculate when the electrons are going to take the jump, and this is what makes this dice really random! OK. And what about the space-graded part?
Well… This dice operates without any microcontroller! It’s all analogic components and logic gates, meaning that this dice can go to outer space! (I think?) It’s one of the requisites, but yeah, it could go to space (I think????).
Oh, and you can select the number of “faces” of the dice! Meaning you can ditch all your boring dices, because you’ve got one to rule over all!
“But @dabecart, going to space? If it’s battery operated, how are you going to charge it?” Glad you’ve asked it. It’s got a solar panel. Yeah… It can also be charged using USB-C!

Useless. Over-engineered. Dubious quality. All seals of @dabecart work!

Hope you enjoy it!

### By @dabecart

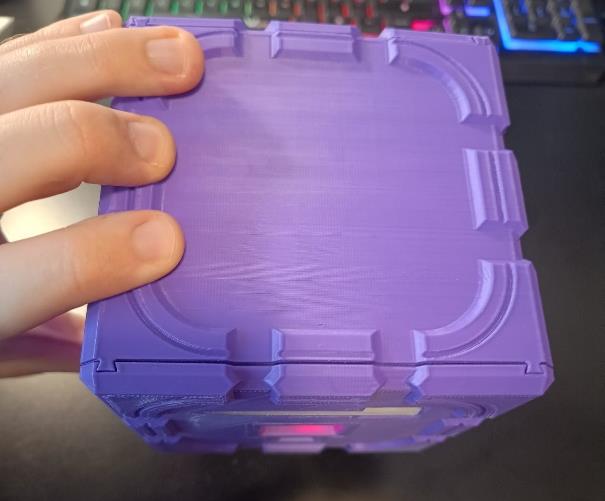
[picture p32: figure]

2 | P a g e

# How to use

Step 1. Powering on the dice.
Tilt the dice more than 90º degrees for 2 seconds until the digits light up.

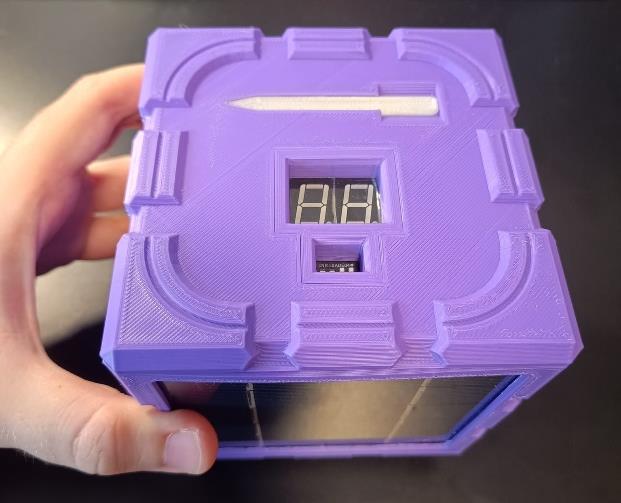
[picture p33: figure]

Step 2. Selecting the number of faces of the dice.
Use the pen to select the number of faces (the maximum number) of the dice using by positioning the individual switches. Use the following table to set the number:
S1 | S2 | S3 | S4 | Faces
OFF OFF OFF OFF | 32
OFF OFF OFF ON | 2
OFF OFF ON OFF | 4
OFF OFF ON ON | 6
OFF ON OFF OFF | 8
OFF ON OFF ON | 10
OFF ON ON OFF | 12
OFF ON ON ON | 14
ON OFF OFF OFF | 16
ON OFF OFF ON | 18
ON OFF ON OFF | 20
ON OFF ON ON | 22
ON ON OFF OFF | 24
ON ON OFF ON | 26
ON ON ON OFF | 28
ON ON ON ON | 30

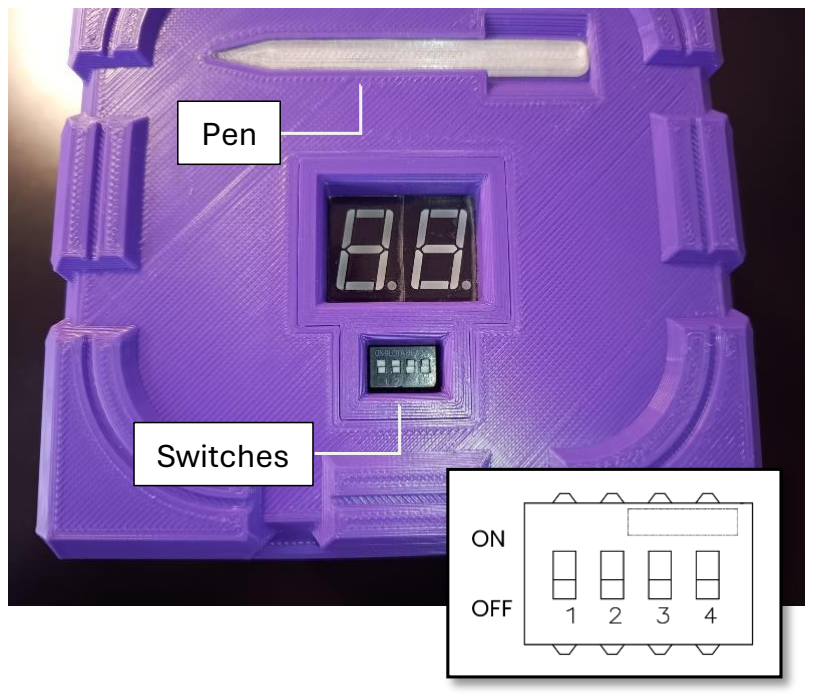
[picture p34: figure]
Pen; Switches
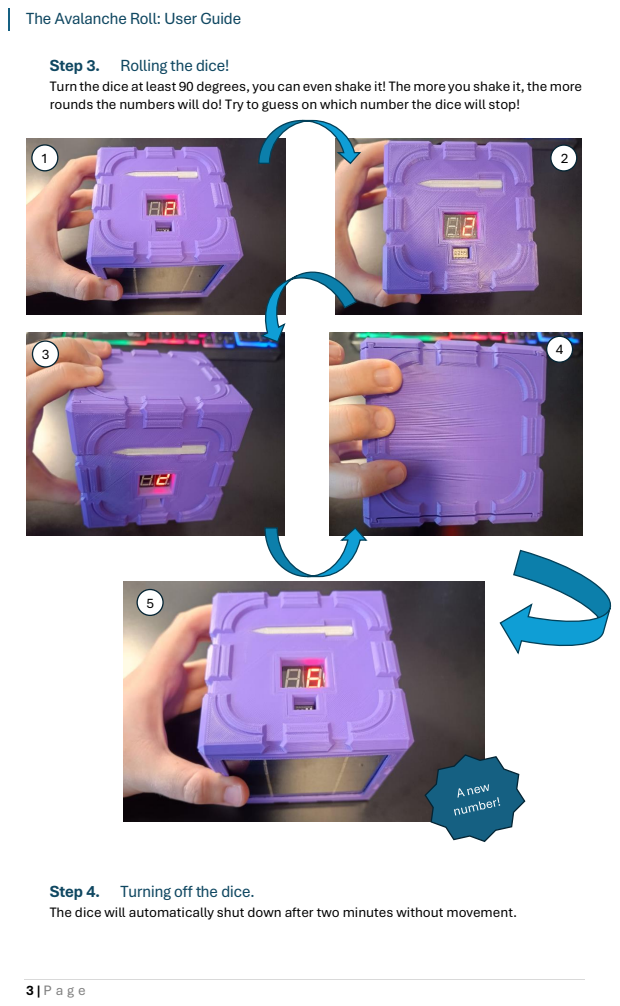
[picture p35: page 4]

Step 3. Rolling the dice!
Turn the dice at least 90 degrees, you can even shake it! The more you shake it, the more
rounds the numbers will do! Try to guess on which number the dice will stop!

Step 4. Turning off the dice.
The dice will automatically shut down after two minutes without movement.

### By @dabecart

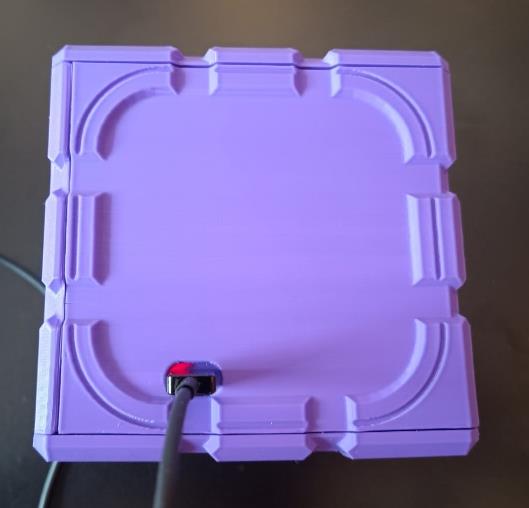
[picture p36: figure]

4 | P a g e
Step 5. Charging the Avalanche Roll.
There are two methods of charging the dice:
5.1 Using the USB C charging point.
The red light will tell you that the dice is charging. When the battery is charged, the dice will turn off this light.
Estimated charging time: 2 hours.

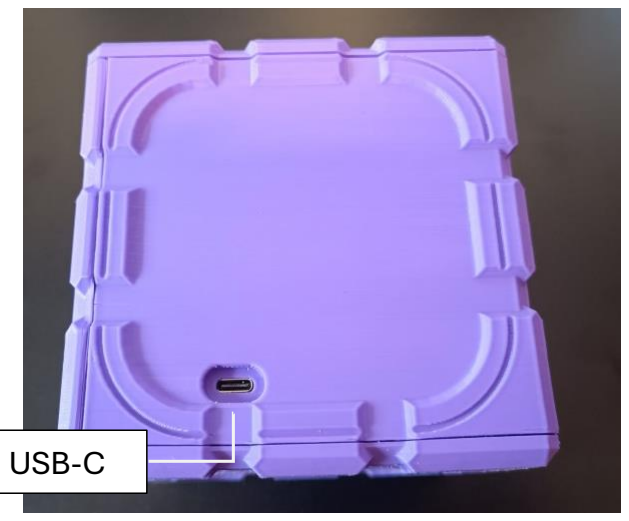
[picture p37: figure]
USB-C

Please note that the dice does not support fast charging and most of the common mobile phone chargers won’t work with the dice. Try using an older charger!

5.2 Using the solar panel.
Important! Do not put under direct sunlight over long periods of time.
The solar panel integrated on the dice will automatically charge the dice so don’t worry if you don’t have a charger at hand!
Estimated charging time: 2 hours on sunny days, 5 hours on cloudier days.
5.3 Using both methods at the same time.
Although not recommended, it is safe to charge it both with the solar panel and an USB-C charger.

## Safety warnings

- If you want to change the battery, bear in mind if the polarity! If the battery is wrongly positioned, ehm… fire :3
- Do not eat. If eaten, you have my utmost admiration.
- I think the dice is sturdy enough to resist some impacts, but please, do not test it if you want to keep the device’s integrity.

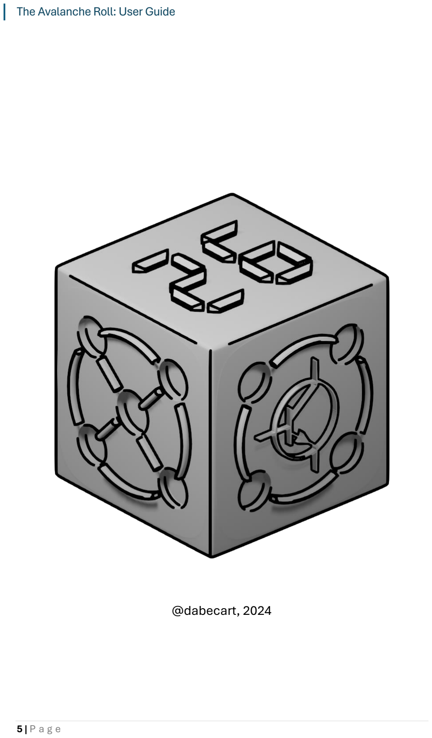
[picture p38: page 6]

5 | P a g e

### @dabecart, 2024

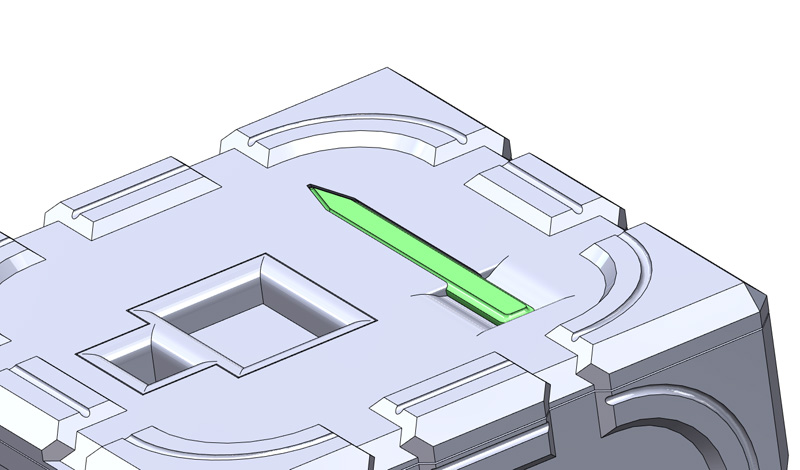
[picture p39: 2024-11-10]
Manual_Renders/render_test/JPEG/Step17.jpg

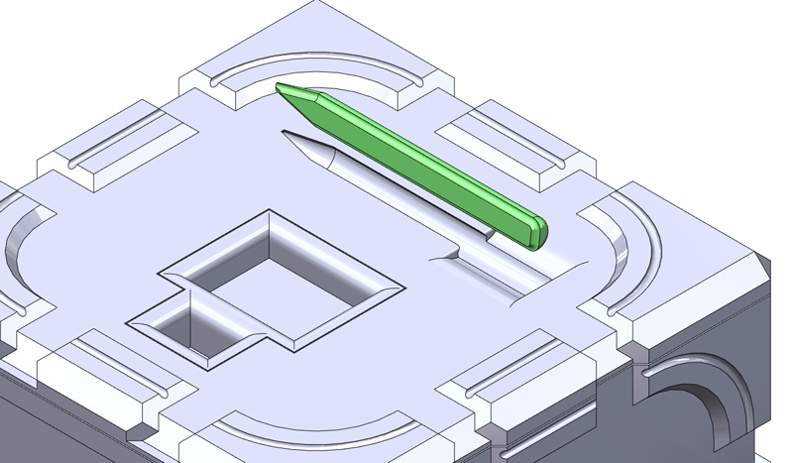
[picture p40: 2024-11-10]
Manual_Renders/render_test/JPEG/Step15.jpg

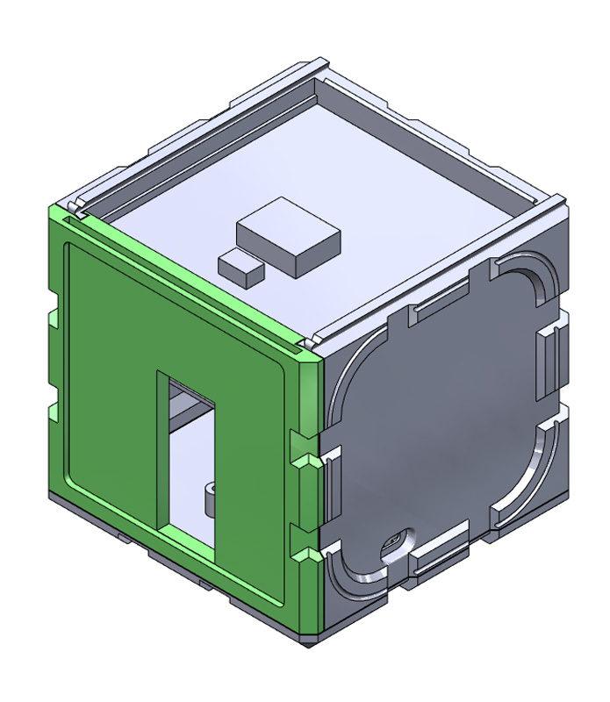
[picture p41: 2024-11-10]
Manual_Renders/render_test/JPEG/Step10.jpg

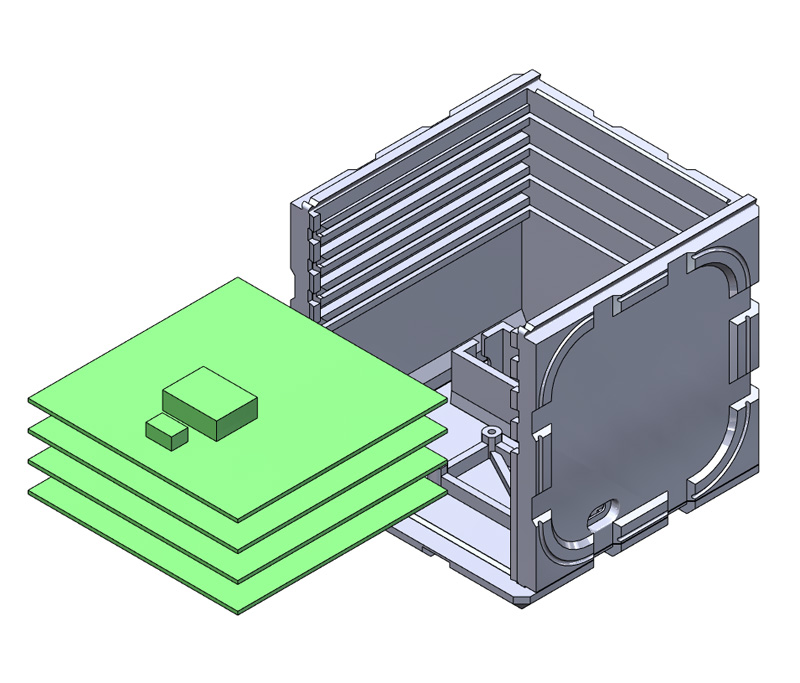
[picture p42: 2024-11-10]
Manual_Renders/render_test/JPEG/Step7.jpg

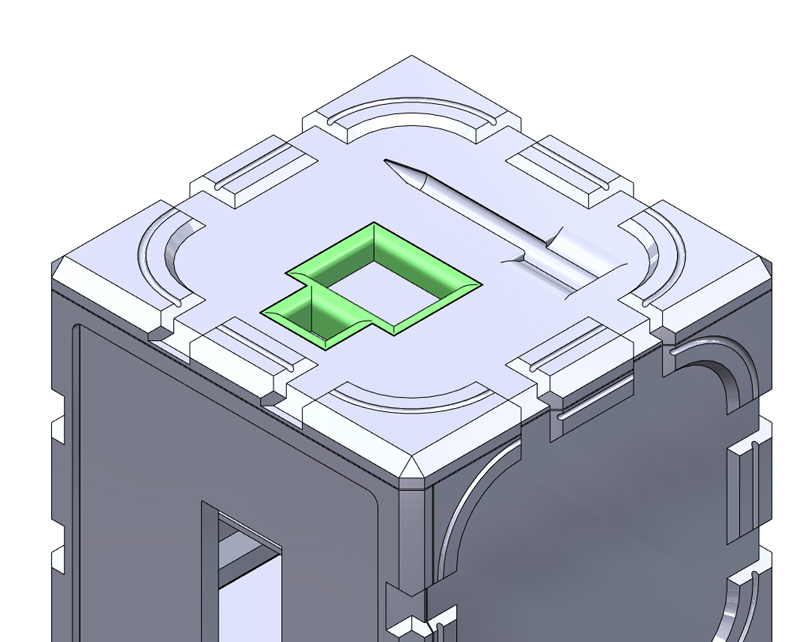
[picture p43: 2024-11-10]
Manual_Renders/render_test/JPEG/Step14.jpg

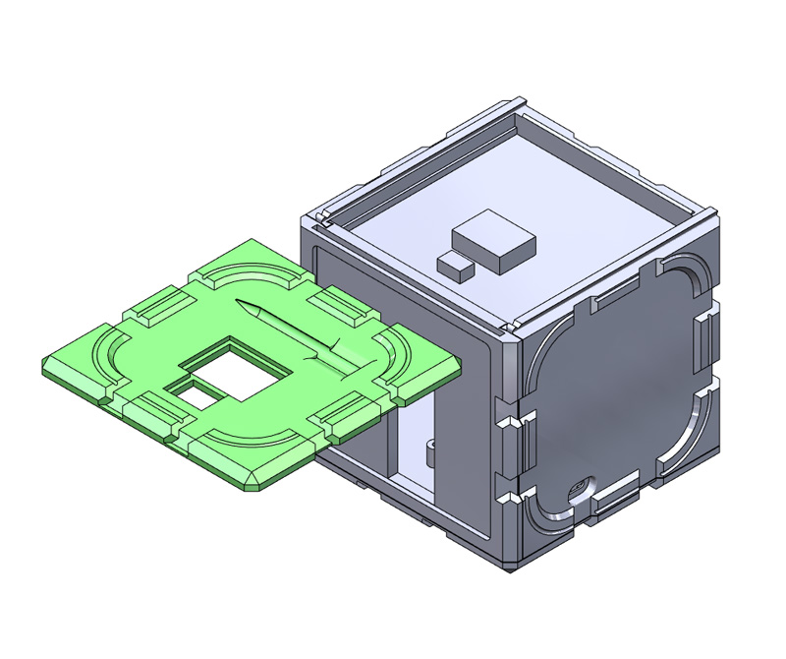
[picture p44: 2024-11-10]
Manual_Renders/render_test/JPEG/Step11.jpg

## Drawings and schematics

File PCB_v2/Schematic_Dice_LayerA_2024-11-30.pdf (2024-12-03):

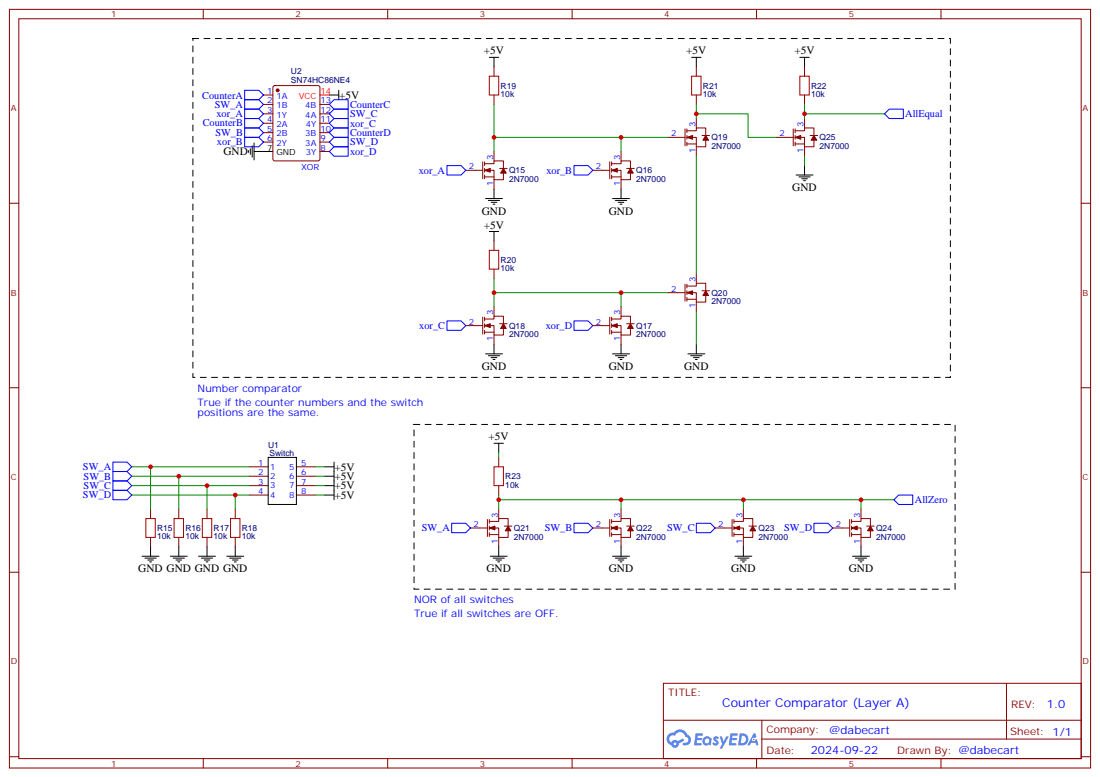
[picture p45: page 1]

Number comparator
True if the counter numbers and the switch
positions are the same.

GND GND

NOR of all switches
True if all switches are OFF.

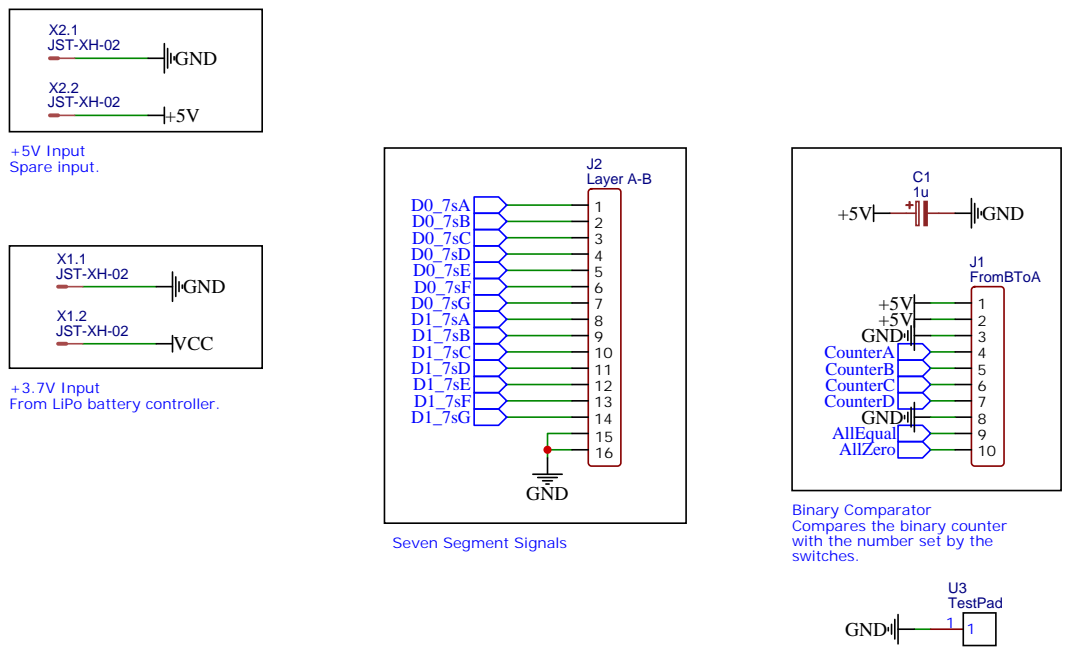
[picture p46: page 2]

+3.7V Input
From LiPo battery controller.

Binary Comparator
Compares the binary counter
with the number set by the
switches.

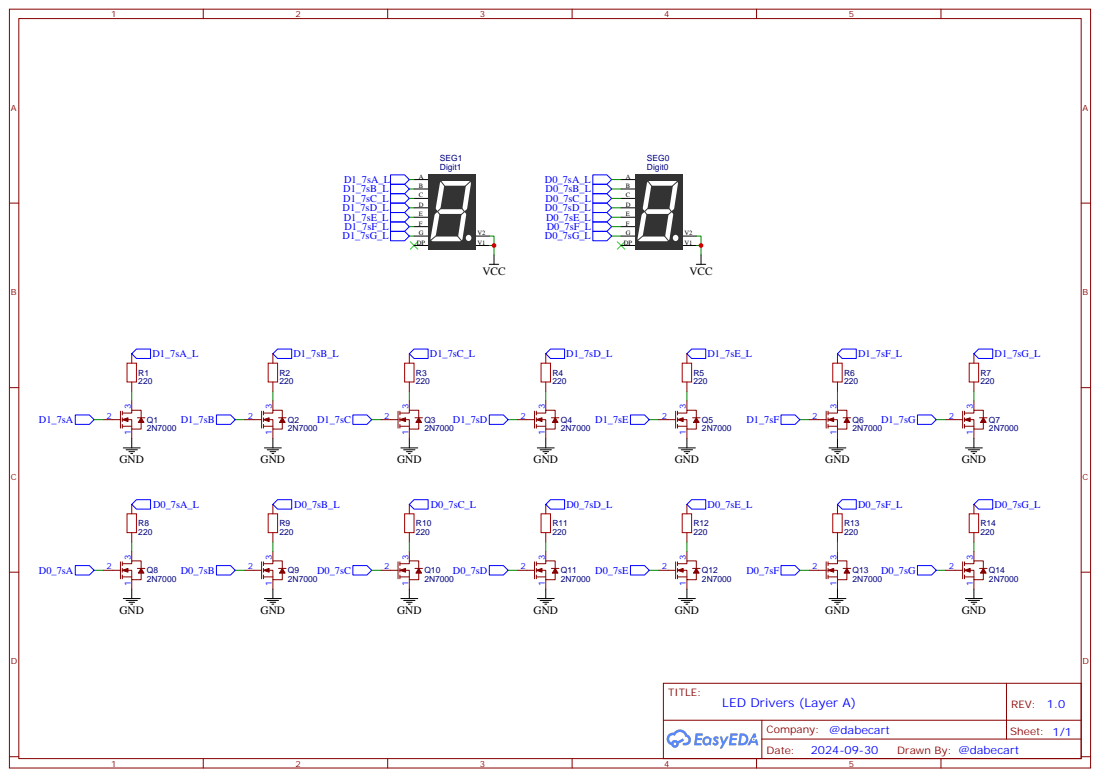
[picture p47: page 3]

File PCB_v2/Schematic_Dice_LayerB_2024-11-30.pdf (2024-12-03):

D0_D | SN74HC08 = AND SN74HC32 = OR

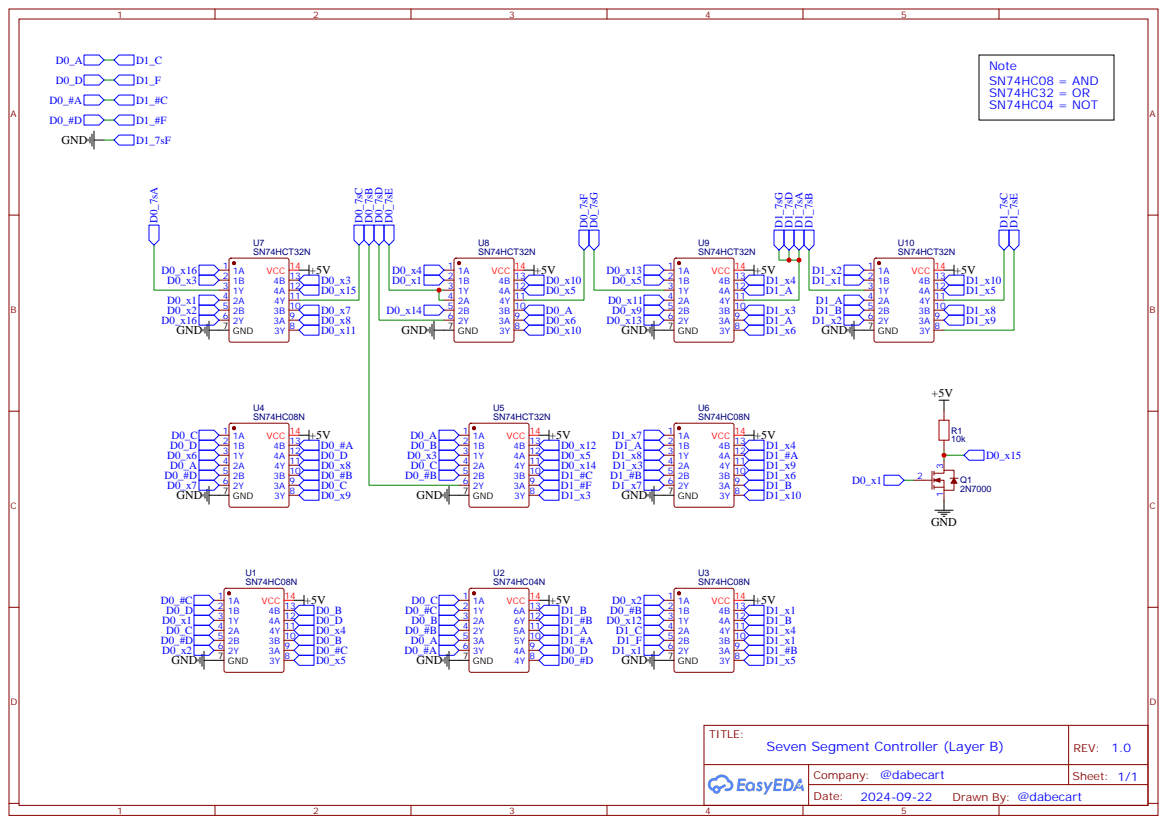
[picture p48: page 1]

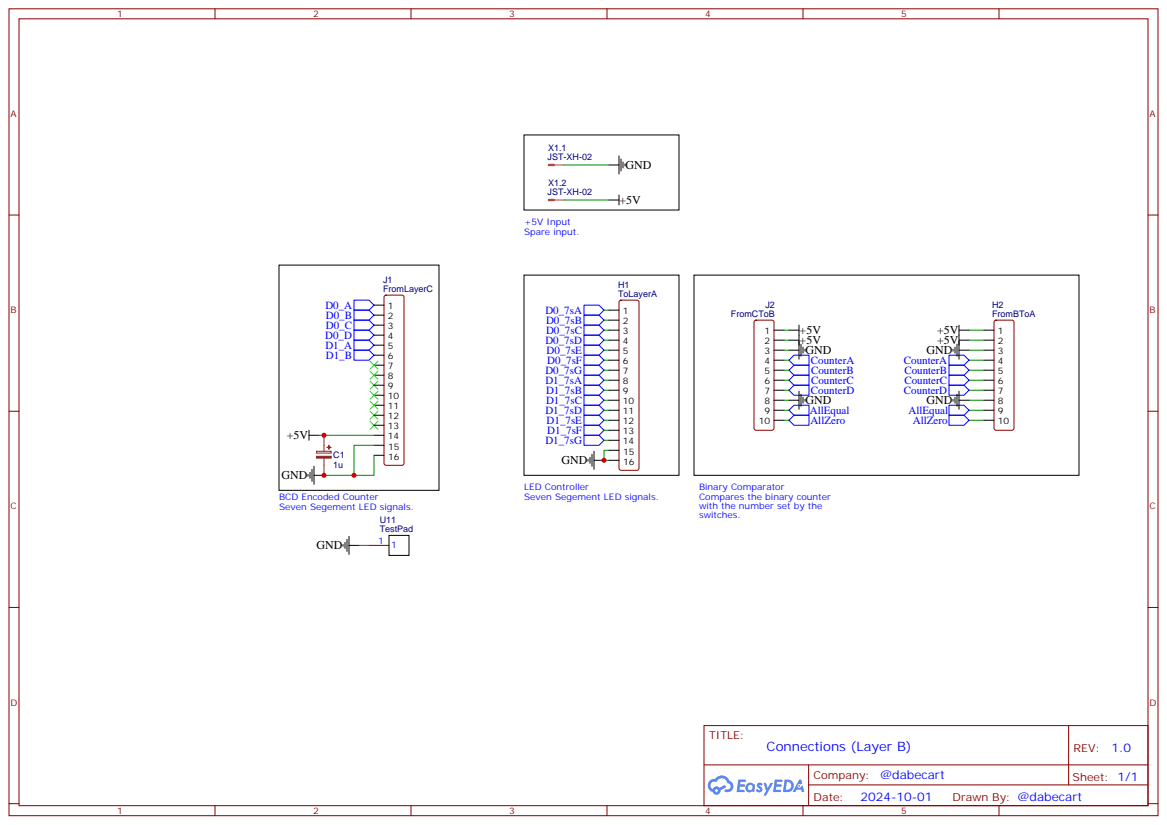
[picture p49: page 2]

Binary Comparator
Compares the binary counter
with the number set by the
switches.

Seven Segement LED signals.

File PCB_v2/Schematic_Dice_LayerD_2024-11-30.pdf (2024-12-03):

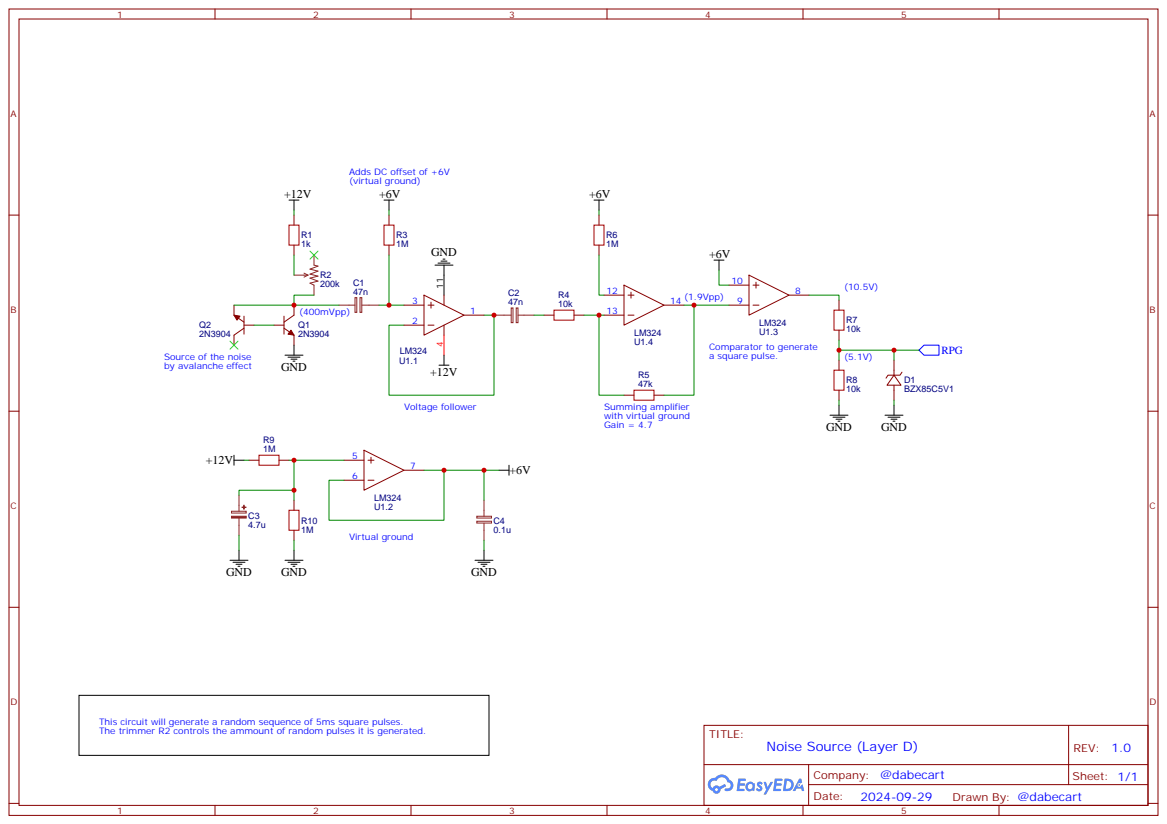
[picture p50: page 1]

Adds DC offset of +6V
(virtual ground)

Source of the noise
by avalanche effect

This circuit will generate a random sequence of 5ms square pulses.
The trimmer R2 controls the ammount of random pulses it is generated.

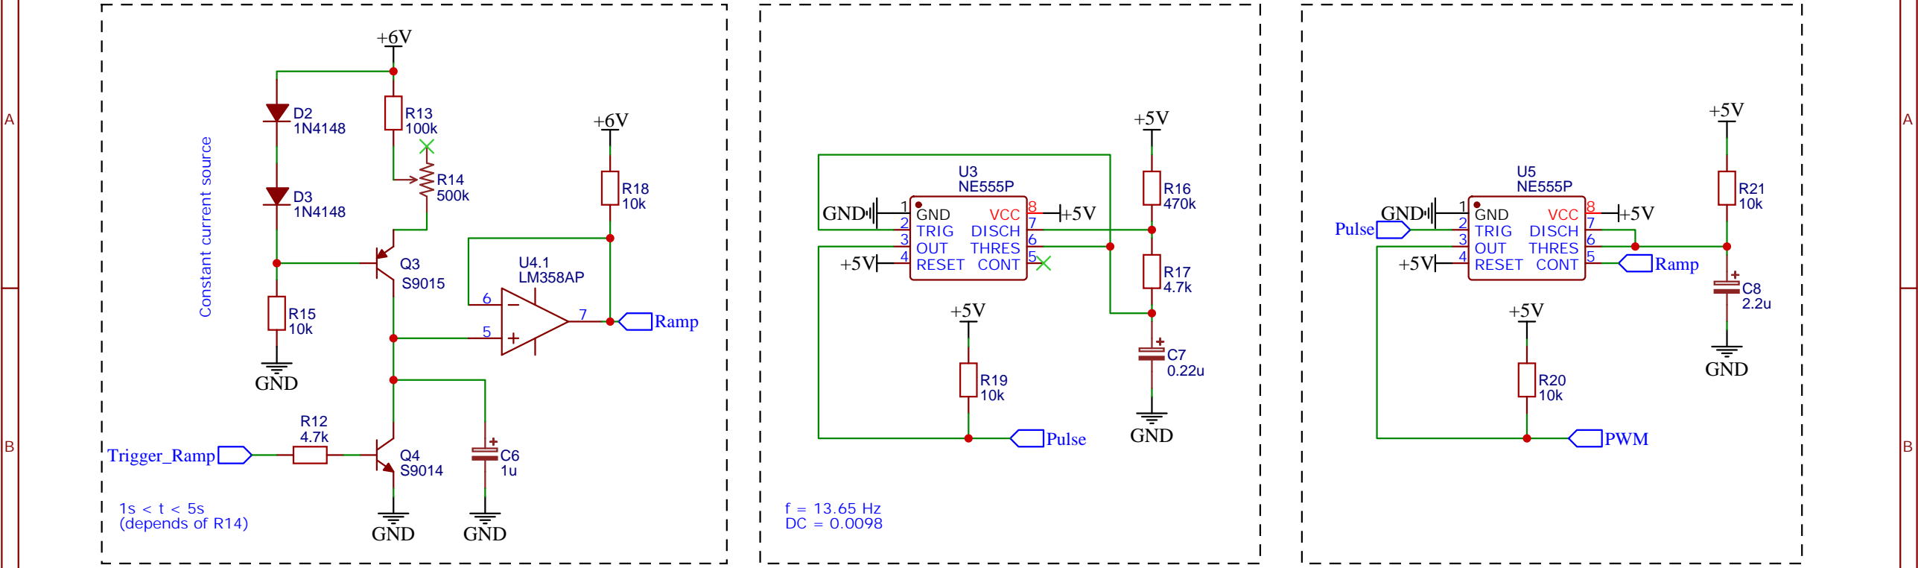
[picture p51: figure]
GND; Trigger_Ramp; GND 1 TRIG 2 OUT 3 RESET 4; CONT 5; THRES 6; DISCH 7; VCC 8 GND; Ramp; Pulse; PWM
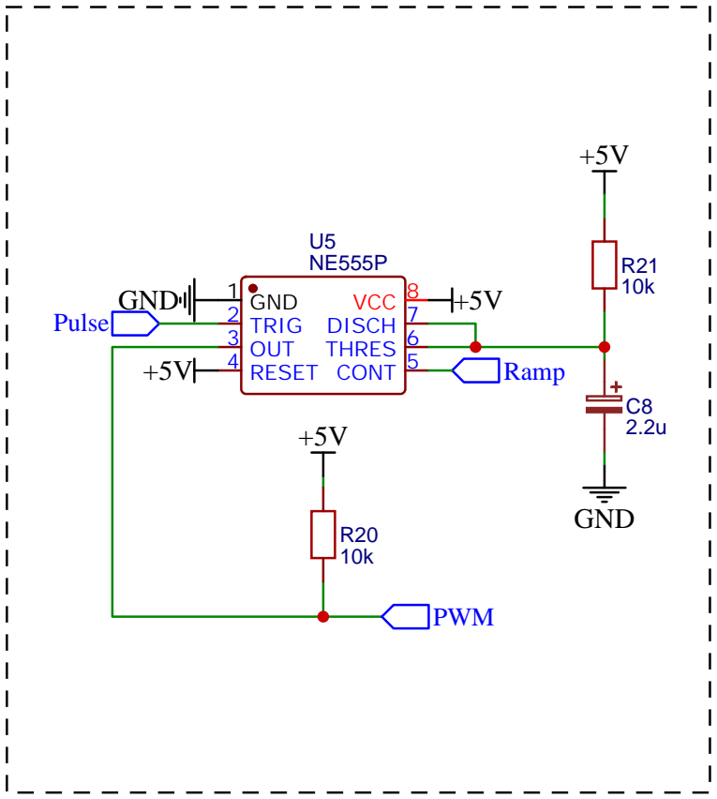
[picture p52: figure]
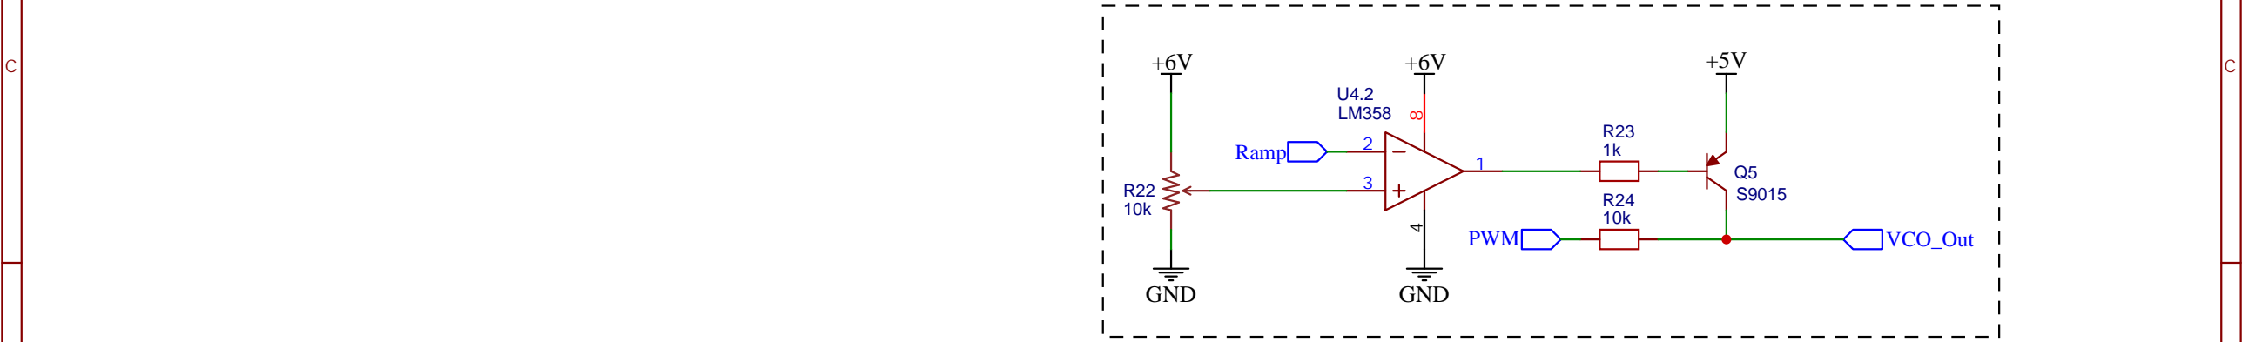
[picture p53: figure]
GND; Ramp; PWM; VCO_Out

D | D

### TITLE:

VCO (Layer D) | REV: 1.0

## Ramp Generator

Creates a rising ramp on a falling edge.
The rise time is calculated as: t = (R13+R14)*C6*Vcc/0.7 This will be the modulating signal to control the duty cycle of the output PWM.

# (depends of R14) Constant current source

Astable multivibrator with a very low duty cycle. Gives the frequency of the output PWM. Frequency: f=1.44/[(R16+2R17)C7]
Duty cycle: DC=Rb/(R16+2R17)

## Pulse generator

Converts the pulse input into a PWM with its duty cycle controlled by a modulating signal. In this case, the output of the ramp generator.
If T is the pulse period, then: R21*C8=T/4
The output DC is directly proportional to the ramp input.

## Modulator

The modulator is incapable of fully generating a duty cycle of 0% or 100%, therefore this stage pulls high the VCO when the ramp is in its idle voltage (HIGH too). R22 will have to be adjusted so the normal output of this stage (VCO_Out) is +5V.

## Output saturation

These circuits are used to create a PWM signal whose duty cycle will normally be 100%. When the tilt switch is triggered, it will make the duty cycle of the PWM fall to almost
0% and then raise slowly when no shaking is applied to the dice.
This PWM will be ANDed to the PWM so that the number stop increasing slowly, but still randomnly until they eventually stop. In other words, when the PWM's DC is 0% (almost) all random pulses will be passed to the counter. When the DC starts raising, less pulses will get through simulating a slow down of the dice, similar to a roullete.

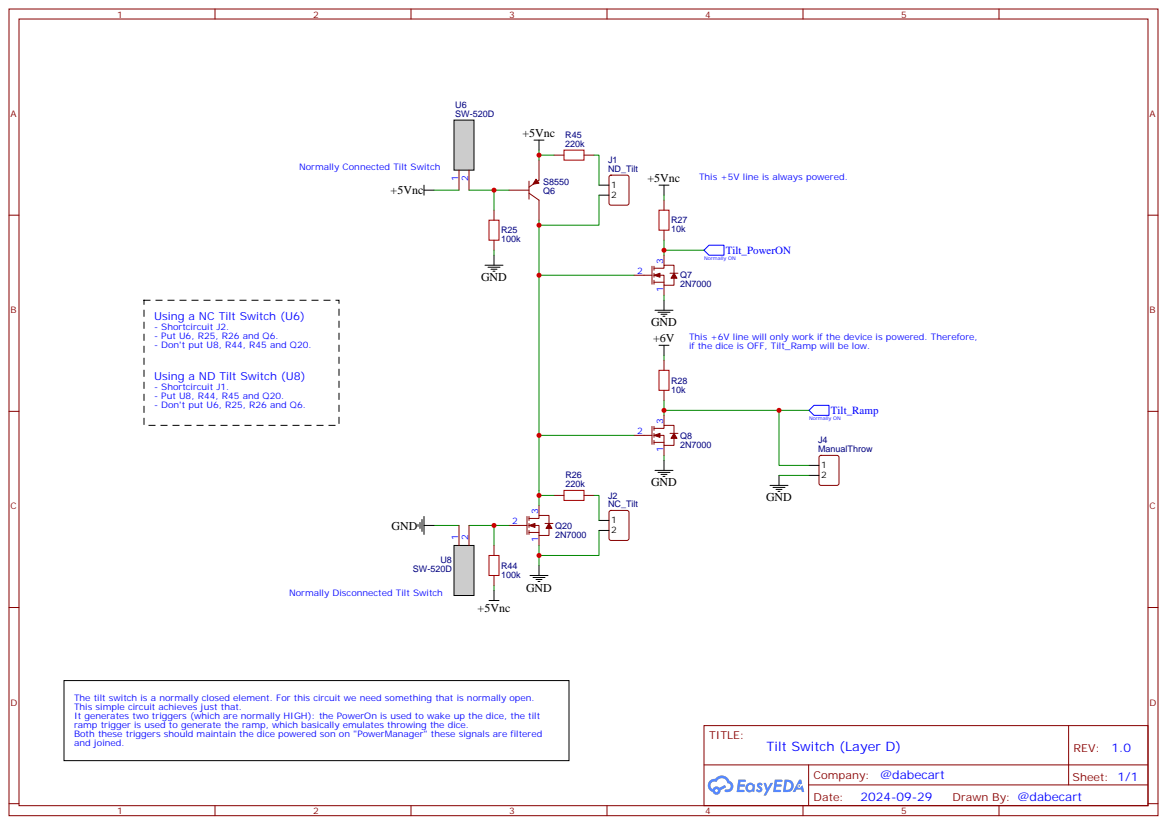
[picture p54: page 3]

Normally Connected Tilt Switch

This +5V line is always powered.

Using a NC Tilt Switch (U6)
- Shortcircuit J2.
- Put U6, R25, R26 and Q6.
- Don't put U8, R44, R45 and Q20.

This +6V line will only work if the device is powered. Therefore,
if the dice is OFF, Tilt_Ramp will be low.

Using a ND Tilt Switch (U8)
- Shortcircuit J1.
- Put U8, R44, R45 and Q20.
- Don't put U6, R25, R26 and Q6.

Normally Disconnected Tilt Switch

The tilt switch is a normally closed element. For this circuit we need something that is normally open.
This simple circuit achieves just that.
It generates two triggers (which are normally HIGH): the PowerOn is used to wake up the dice, the tilt
ramp trigger is used to generate the ramp, which basically emulates throwing the dice.
Both these triggers should maintain the dice powered son on "PowerManager" these signals are filtered
and joined.

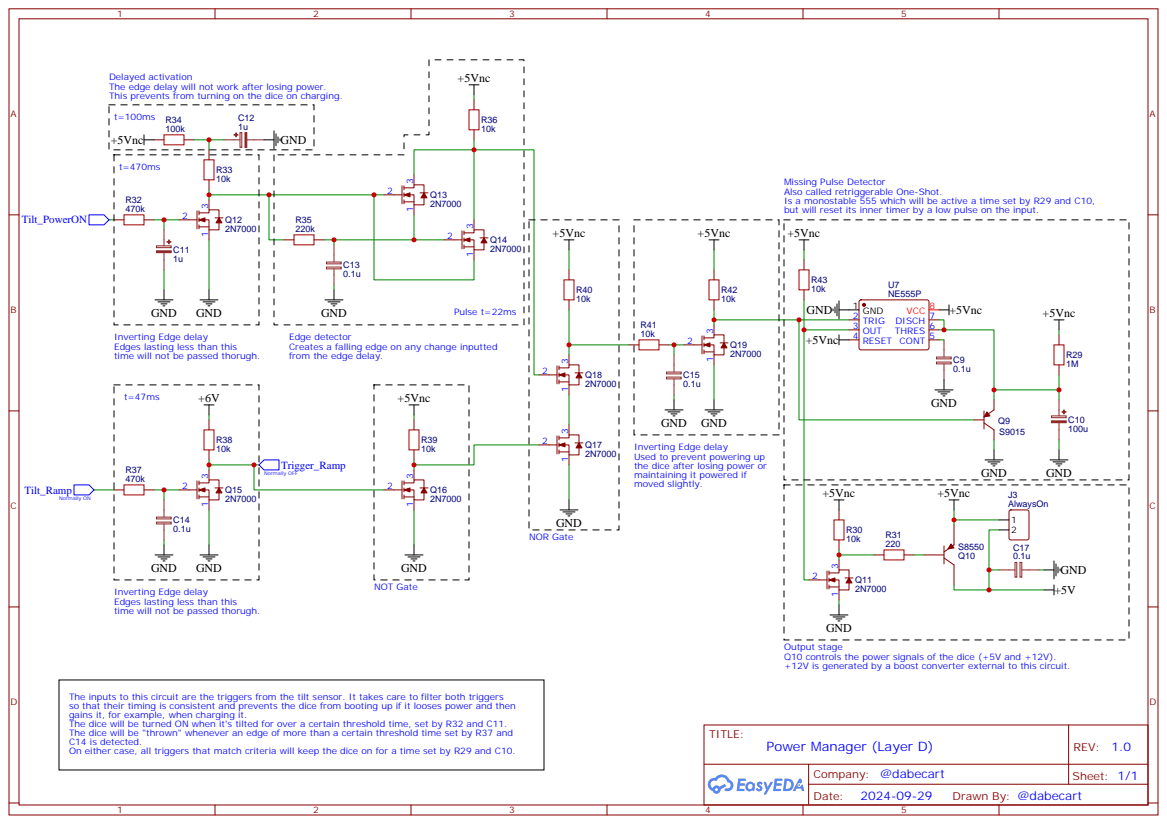
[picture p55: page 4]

Delayed activation
The edge delay will not work after losing power.
This prevents from turning on the dice on charging.

Missing Pulse Detector
Also called retriggerable One-Shot.
Is a monostable 555 which will be active a time set by R29 and C10,
but will reset its inner timer by a low pulse on the input.
+5Vnc

Inverting Edge delay
Edges lasting less than this
time will not be passed thorugh.

Edge detector
Creates a falling edge on any change inputted
from the edge delay.

Used to prevent powering up
the dice after losing power or
maintaining it powered if
moved slightly.

Output stage
Q10 controls the power signals of the dice (+5V and +12V).
+12V is generated by a boost converter external to this circuit.

The inputs to this circuit are the triggers from the tilt sensor. It takes care to filter both triggers
so that their timing is consistent and prevents the dice from booting up if it looses power and then
gains it, for example, when charging it.
The dice will be turned ON when it's tilted for over a certain threshold time, set by R32 and C11.
The dice will be "thrown" whenever an edge of more than a certain threshold time set by R37 and
C14 is detected.
On either case, all triggers that match criteria will keep the dice on for a time set by R29 and C10.

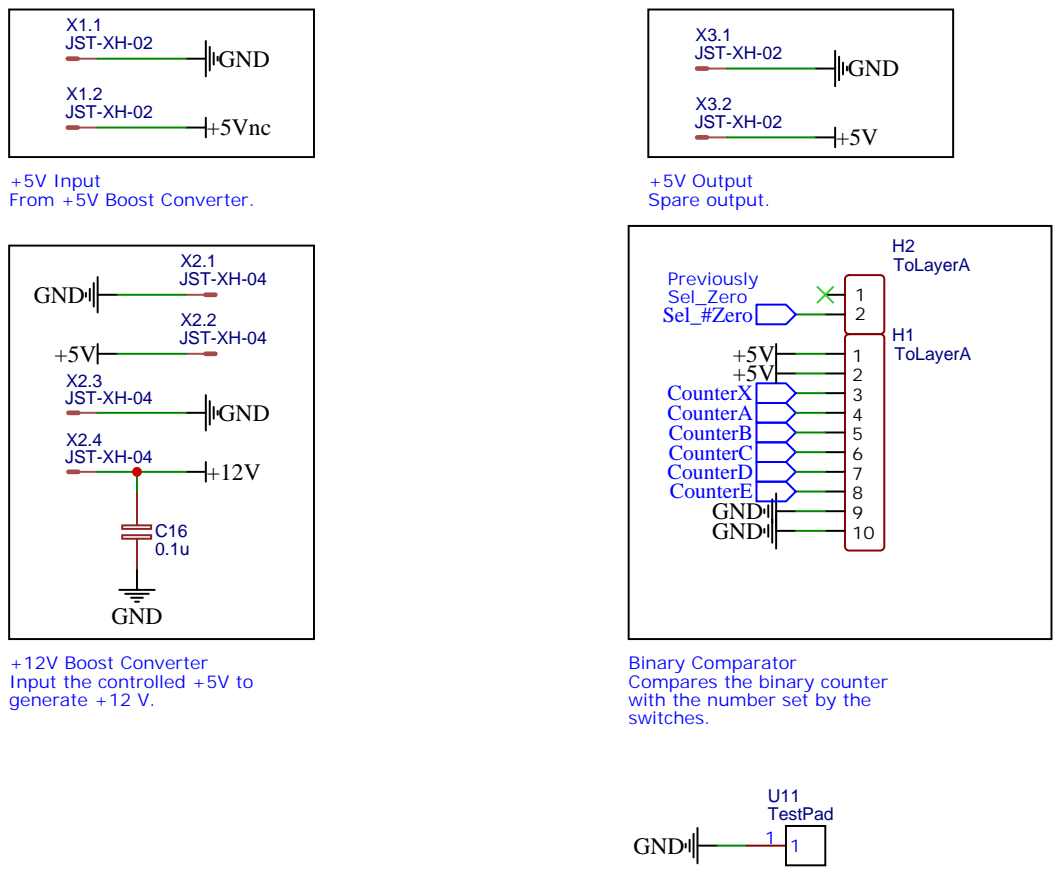
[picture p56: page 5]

+12V Boost Converter
Input the controlled +5V to
generate +12 V.

Binary Comparator
Compares the binary counter
with the number set by the
switches.


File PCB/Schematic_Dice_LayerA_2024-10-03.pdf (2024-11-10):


Number comparator
True if the counter numbers and the switch
positions are the same.

GND GND

NOR of all switches
True if all switches are OFF.

Drawn By: Daniel B jar Caballero


+3.7V Input
From LiPo battery controller.

Binary Comparator
Compares the binary counter
with the number set by the
switches.


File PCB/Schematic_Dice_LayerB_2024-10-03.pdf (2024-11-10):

D0_D | SN74HC08 = AND SN74HC32 = OR



Binary Comparator
Compares the binary counter
with the number set by the
switches.

Seven Segement LED signals.

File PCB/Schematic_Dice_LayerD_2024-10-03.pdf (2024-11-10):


Adds DC offset of +6V
(virtual ground)

Source of the noise
by avalanche effect

This circuit will generate a random sequence of 5ms square pulses.
The trimmer R2 controls the ammount of random pulses it is generated.

GND; Trigger_Ramp; GND 1 TRIG 2 OUT 3 RESET 4; CONT 5; THRES 6; DISCH 7; VCC 8 GND; Ramp; Pulse; PWM
GND; Ramp; PWM; VCO_Out

D | D

### TITLE:

VCO (Layer D) | REV: 1.0

## Ramp Generator

Creates a rising ramp on a falling edge.
The rise time is calculated as: t = (R13+R14)*C6*Vcc/0.7 This will be the modulating signal to control the duty cycle of the output PWM.

# (depends of R14) Constant current source

Astable multivibrator with a very low duty cycle. Gives the frequency of the output PWM. Frequency: f=1.44/[(R16+2R17)C7]
Duty cycle: DC=Rb/(R16+2R17)

## Pulse generator

Converts the pulse input into a PWM with its duty cycle controlled by a modulating signal. In this case, the output of the ramp generator.
If T is the pulse period, then: R21*C8=T/4
The output DC is directly proportional to the ramp input.

## Modulator

The modulator is incapable of fully generating a duty cycle of 0% or 100%, therefore this stage pulls high the VCO when the ramp is in its idle voltage (HIGH too). R22 will have to be adjusted so the normal output of this stage is +5V.

## Output saturation

These circuits are used to create a PWM signal whose duty cycle will normally be 100%. When the tilt switch is triggered, it will make the duty cycle of the PWM fall to almost
0% and then raise slowly when no shaking is applied to the dice.
This PWM will be ANDed to the PWM so that the number stop increasing slowly, but still randomnly until they eventually stop. In other words, when the PWM's DC is 0% (almost) all random pulses will be passed to the counter. When the DC starts raising, less pulses will get through simulating a slow down of the dice, similar to a roullete.


Normally Connected Tilt Switch

This +5V line is always powered.

Using a NC Tilt Switch (U6)
- Shortcircuit J2.
- Put U6, R25, R26 and Q6.
- Don't put U8, R44, R45 and Q20.

This +6V line will only work if the device is powered. Therefore,
if the dice is OFF, Tilt_Ramp will be low.

Using a ND Tilt Switch (U8)
- Shortcircuit J1.
- Put U8, R44, R45 and Q20.
- Don't put U6, R25, R26 and Q6.

Normally Disconnected Tilt Switch

The tilt switch is a normally closed element. For this circuit we need something that is normally open.
This simple circuit achieves just that.
It generates two triggers (which are normally HIGH): the PowerOn is used to wake up the dice, the tilt
ramp trigger is used to generate the ramp, which basically emulates throwing the dice.
Both these triggers should maintain the dice powered son on "PowerManager" these signals are filtered
and joined.


Delayed activation
The edge delay will not work after losing power.
This prevents from turning on the dice on charging.

Missing Pulse Detector
Also called retriggerable One-Shot.
Is a monostable 555 which will be active a time set by R29 and C10,
but will reset its inner timer by a low pulse on the input.
+5Vnc

Inverting Edge delay
Edges lasting less than this
time will not be passed thorugh.

Edge detector
Creates a falling edge on any change inputted
from the edge delay.

Used to prevent powering up
the dice after losing power or
maintaining it powered if
moved slightly.

Output stage
Q10 controls the power signals of the dice (+5V and +12V).
+12V is generated by a boost converter external to this circuit.

The inputs to this circuit are the triggers from the tilt sensor. It takes care to filter both triggers
so that their timing is consistent and prevents the dice from booting up if it looses power and then
gains it, for example, when charging it.
The dice will be turned ON when it's tilted for over a certain threshold time, set by R32 and C11.
The dice will be "thrown" whenever an edge of more than a certain threshold time set by R37 and
C14 is detected.
On either case, all triggers that match criteria will keep the dice on for a time set by R29 and C10.


+12V Boost Converter
Input the controlled +5V to
generate +12 V.

Binary Comparator
Compares the binary counter
with the number set by the
switches.

Drawn By: Daniel B jar Caballero






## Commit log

2024-11-10 Welcome to the world Avalanche Roll!
    [BOM_Dice_LayerA_2024-10-03.csv, BOM_Dice_LayerB_2024-10-03.csv, BOM_Dice_LayerC_2024-10-03.csv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]
2024-12-01 Version 2.0 of the Avalanche Roll!
    [BOM_Dice_LayerA_2024-10-03.csv, BOM_Dice_LayerA_2024-11-15.csv, BOM_Dice_LayerB_2024-10-03.csv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]
